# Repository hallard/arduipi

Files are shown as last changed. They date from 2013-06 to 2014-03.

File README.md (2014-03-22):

ArduiPi
=======

ArduiPi is a shield for Raspberry Pi that brings Arduino low level extented I/O to Raspberry Pi.

Detailed Description
====================

Everything is documented on this decicated [page][3]

top  
bottom

**Schematic**  
schematic

**Board**  
![board] (https://raw.github.com/hallard/arduipi/master/ArduiPi-V1.1-brd.png)

Check out news and other projects on my [blog][4] 

[3]: http://hallard.me/arduipi-the-shield-that-brings-arduino-to-raspberry-pi/
[4]: http://hallard.me

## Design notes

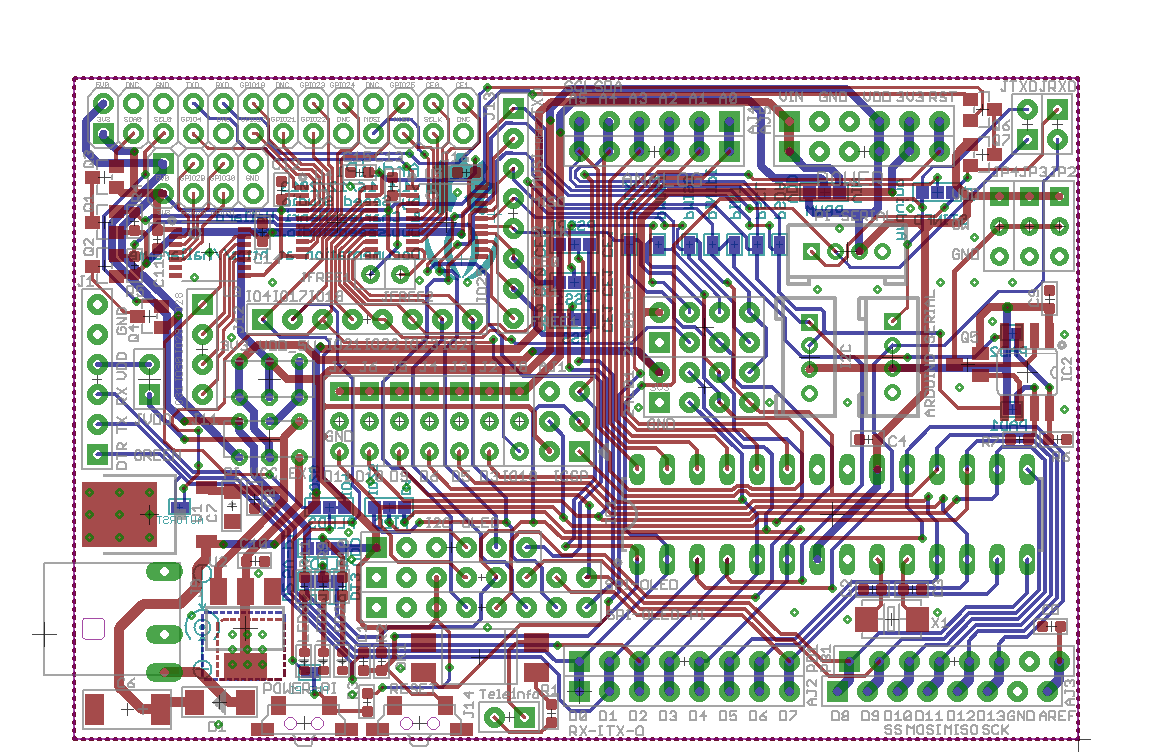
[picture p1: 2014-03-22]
ArduiPi-V1.1-brd.png

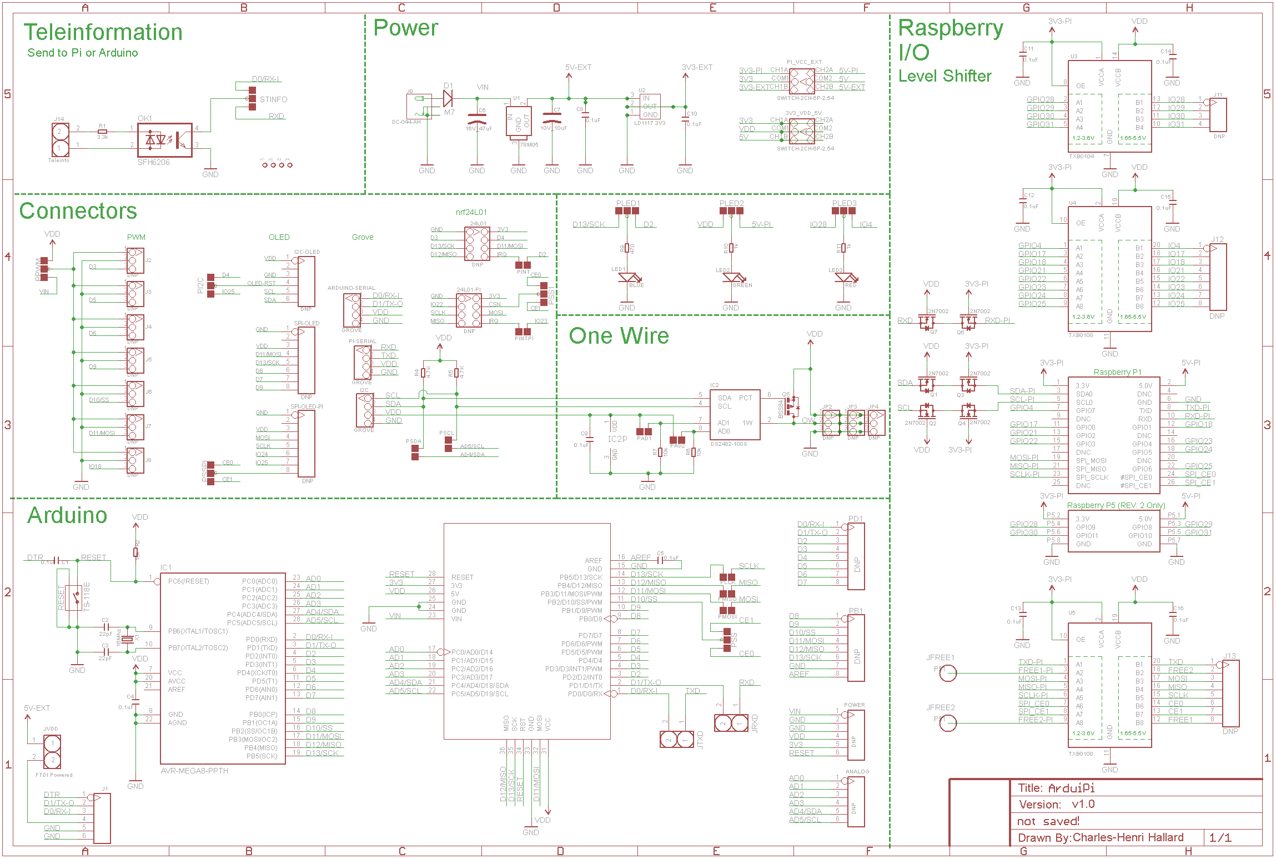
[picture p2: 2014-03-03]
ArduiPi-V1.0-sch.png

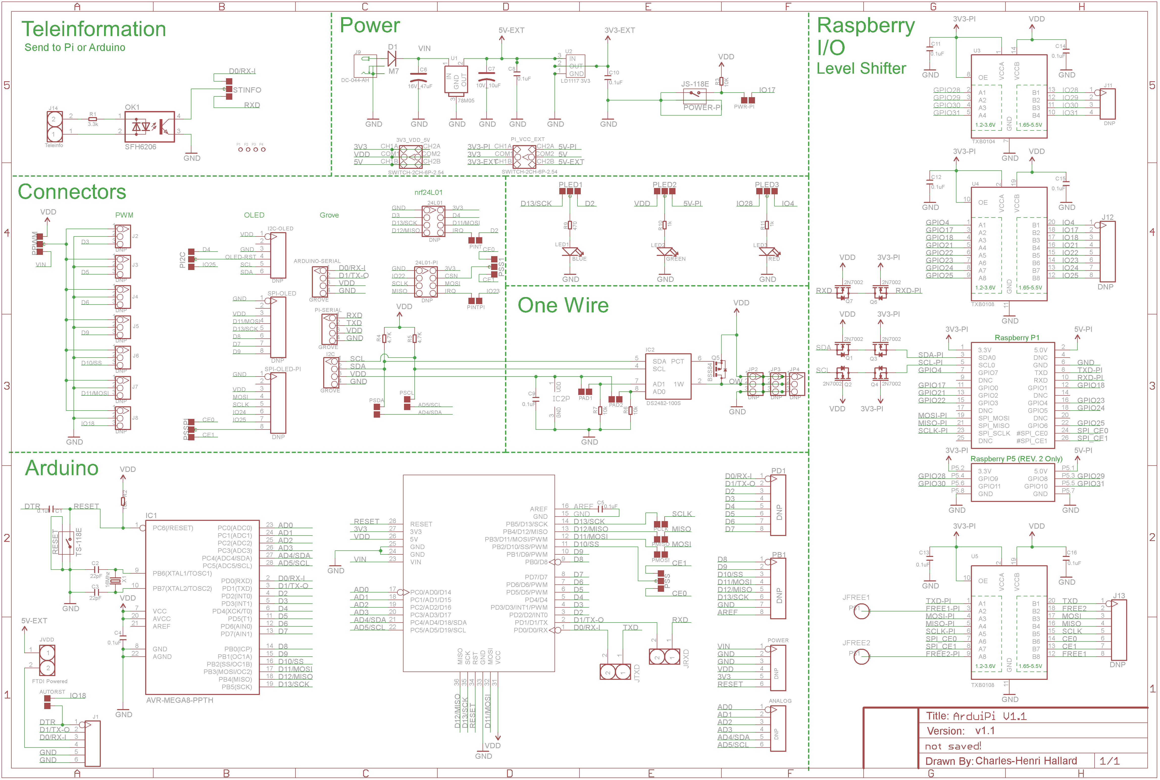
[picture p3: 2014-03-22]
ArduiPi-V1.1-sch.png

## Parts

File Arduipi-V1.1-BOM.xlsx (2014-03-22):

Qty | Part | Value | Package | Seeed Part number | Digikey Part Number | Description
2 | U4, U5 | TXB0108 | TSSOP20 | 156001001 TXB0108PW | 296-21527-1-ND (http://www.digikey.com/product-detail/en/TXB0108PWR/296-21527-1-ND/1305700) | 8-Bit Bi-Directional Level Shifter
1 | U3 | TXB0104 | TSSOP14 | 156002001 TXB0104PWR | 296-21929-1-ND (http://www.digikey.com/product-detail/en/TXB0104PWR/296-21929-1-ND/1629282) | 4-Bit Bi-Directional Level Shifter
1 | OK1 | SFH6206 | DIL4-SMD |  | SFH6206-2T (http://www.digikey.com/product-detail/en/SFH6206-2T/SFH6206-2T-ND/1738581) | Optocoupler, Phototransistor Output, AC Input
6 | Q1, Q2, Q3, Q4, Q6, Q7 | 2N7002 | SOT23 | 044008001
1 | Q5 | CJ2305 | SOT23 | 0440210P1
1 | POWER PI | TS-1188E | 4P-SMD-7X3.5X3.5H | 3100060P1 |  | Switch to power down PI
1 | RESET | TS-1188E | 4P-SMD-7X3.5X3.5H | 3100060P1 |  | Reset Switch, same than the one present on Seeeduino V3
1 | IC2 | DS2482-100S | SO08 |  | DS2482S-100+-ND (http://www.digikey.com/product-detail/en/DS2482S-100%2B/DS2482S-100%2B-ND/1197435) | I2C to 1-Wire Host Adapter/Line Driver
2 | 3V3_VDD_5V | SWITCH-2CH-6P-2.54 | 6P-2CH-2.54-7.6X3.0 | 301002001 |  | Same than the two present on Seeeduino V3
2 | PI_VCC_EXT | SWITCH-2CH-6P-2.54 | 6P-2CH-2.54-7.6X3.0 | 301002001 |  | Same than the two present on Seeeduino V3
1 | U2 | CJT1117-3.3 | SOT-223 | 1310190P1
1 | U1 | CJ78M05 | TO252 | 1300040P1
3 | ARDUINO-SERIAL, I2C, PI-SERIAL | GOVE | 4P-LEADED-2.0 | 3470130P1 |  | Grove Connector, the same than on the Seeeduino V3
1 | J9 | DC-044-AH | DC-404 | 3410010P1 |  | Power Connector, the same than on the Seeeduino V3
12 | C1, C4, C5, C8, C9, C10, C11, C12, C13, C14, C15, C16 | 100nF | 0603 | 0100020P1 |  | Standard surface mount Ceramic Capacitor
1 | IC1 | DIP IC Socket | 2X14P-2.54 Row Spacing 7.62mm | 349003001
1 | insert in IC1 Socket | ATMEGA328P-PU | 28-DIP | 1030050P1 need burn bootloader
2 | C2, C3 | 22pF | 0603 | 0100620P1 |  | Capacitor that goes with AVR crystal
1 | X1 | 16Mhz | 2P-SMD-5X3.2 | 0500290P1 |  | Crystal For AVR
1 | R1 | 1.2k | 0603 | 001095001 |  | Standard surface mount resistor
2 | R6, R7 | 10k | 0603 | 0010170P1 |  | Standard surface mount resistor
1 | R3 | 10k | 0603 | 0010170P1 |  | Standard surface mount resistor
1 | R2 | 10k | 0603 | 0010170P1 |  | Standard surface mount resistor
2 | R4, R5 | 4.7K | 0603 | 0010030P1 |  | Standard surface mount resistor
1 | R9 | 470 | 0603 |  |  | Standard surface mount resistor
2 | R10, R11 | 1K | 0603 |  |  | Standard surface mount resistor
1 | LED1 | BLUE | 0603 | 0330060P1 |  | Standard surface mount BLUE LED
1 | LED2 | GREEN | 0603 | 0330010P1 |  | Standard surface mount GREEN LED
1 | LED3 | RED | 0603 | 0330020P1 |  | Standard surface mount RED LED
1 | D1 | 1N4004 | D2010 | 030003001 |  | Standard diode
1 | C7 | 10uF | CPOL-AVX-A-10UF-10V | 0130040P1 |  | Standard Electrolytic Capacitor
1 | C6 | 47uF | CPOL-AVX-C-47UF-16V | 013015001 |  | Standard Electrolytic Capacitor
1 | PB1 | 2.54-8p female | 8P-2.54 | 3460590P1 |  | Arduino headers, same than on Seeeduino V3
1 | POWER | 2.54-6p female | 6P-2.54-65/35MIL | 346057001 |  | Arduino headers, same than on Seeeduino V3
1 | PD1 | 2.54-8p female | 8P-2.54 | 3460590P1 |  | Arduino headers, same than on Seeeduino V3
1 | ANALOG | 2.54-6p female | 6P-2.54-65/35MIL | 346057001 |  | Arduino headers, same than on Seeeduino V3
1 | RASPBERRY P1 | 2.54-2x13p female |  | 2x13p long female header |  | 2x13 double row 26 pins Raspberry PI Connector
1 | J1 (FTDI connector) | 2.54-6p male | 6P-2.54 | 346075001 | HEADER-6P-2.54 | 6 pin FTDI Header
1 | RASPBERRY P5 | DNP |  | 2x4p long female header |  | DNP
1 | PPWM | DNP | 3P-SMD |  | Solder PAD
1 | PSSPI | DNP | 3P-SMD |  | Solder PAD
7 | J2, J3, J4, J5, J6, J7, J8 | DNP | 3P-2.54 |  | HEADER-3P-2.54
2 | SPI-OLED, SPI-OLED-PI | DNP | 8P-2.54 |  | HEADER-8P-2.54
1 | I2C-OLED | DNP | 6P-2.54 |  | HEADER-6P-2.54
3 | PLED1, PLED2, PLED3 | DNP | 3P-SMD |  | Solder PAD
2 | PAD1, PAD2 | DNP | 2P-SMD |  | Solder PAD
2 | 24L01, 24L01-PI | DNP | 2X4P-2.54 |  | HEADER-2X4P-2.54
2 | PINT, PINT-PI | DNP | 2P-SMD |  | Solder PAD
1 | PSS1 | DNP | 3P-SMD |  | Solder PAD
3 | JP2,JP3,JP4 | DNP | 3P-2.54 |  | HEADER-3P-2.54
1 | PCLK | DNP | 2P-SMD |  | Solder PAD
1 | PMISO | DNP | 2P-SMD |  | Solder PAD
1 | PMOSI | DNP | 2P-SMD |  | Solder PAD
1 | PSS | DNP | 3P-SMD |  | Solder PAD
3 | JVDD, JRXD, JTXD | DNP | 2P-2.54 |  | HEADER-2P-2.54
1 | J14 | DNP | 2P-2.54 |  | HEADER-2P-2.54
1 | J11 | DNP | 4P-2.54 |  | HEADER-4P-2.54
2 | J12, J13 | DNP | 8P-2.54 |  | HEADER-8P-2.54
2 | JFREE1, JFREE2 | DNP | HOLE |  | HOLE
1 | STINFO | DNP | 3P-SMD |  | Solder PAD
1 | PWR-PI | DNP | 2P-SMD |  | Solder PAD
1 | AUTORST | DNP | 2P-SMD |  | Solder PAD
2 | PSDA, PSCL | DNP | 2P-SMD |  | Solder PAD

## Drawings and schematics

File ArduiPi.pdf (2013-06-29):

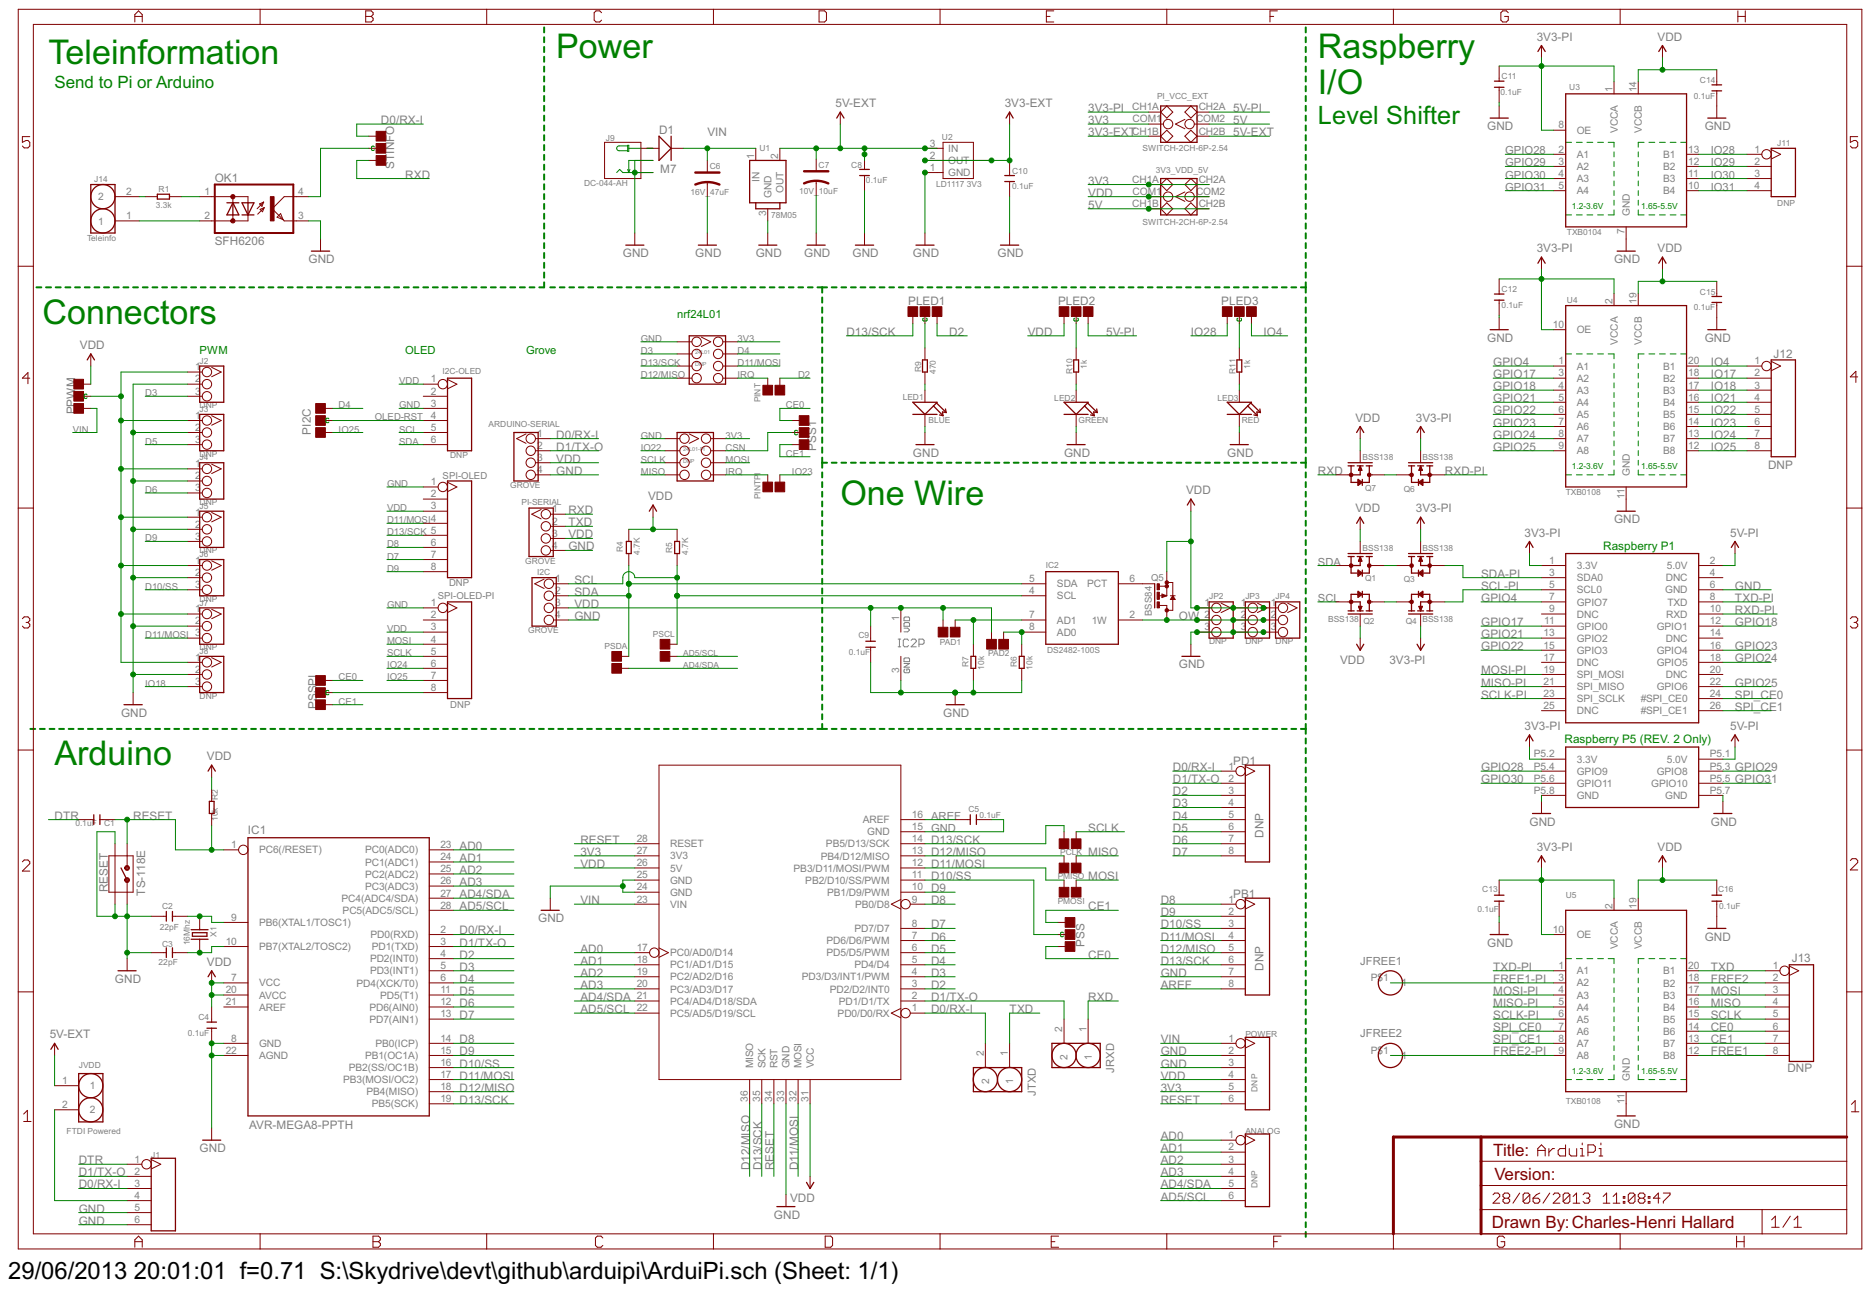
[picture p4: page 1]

Send to Pi or Arduino

AD4/SDA AD5/SCL | 9 PB1/D9/PWM D8 8 PB0/D8 | PMOSI D9 2

Drawn By:Charles-Henri Hallard

29/06/2013 20:01:01 f=0.71 S:\Skydrive\devt\github\arduipi\ArduiPi.sch (Sheet: 1/1)

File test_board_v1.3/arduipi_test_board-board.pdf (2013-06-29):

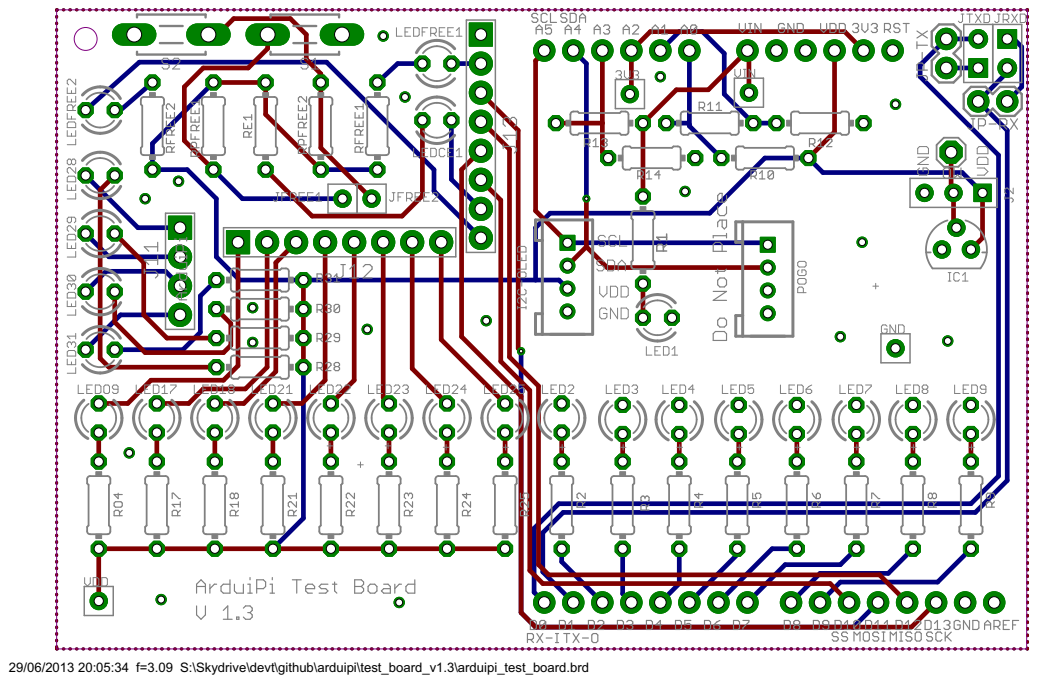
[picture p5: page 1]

29/06/2013 20:05:34 f=3.09 S:\Skydrive\devt\github\arduipi\test_board_v1.3\arduipi_test_board.brd

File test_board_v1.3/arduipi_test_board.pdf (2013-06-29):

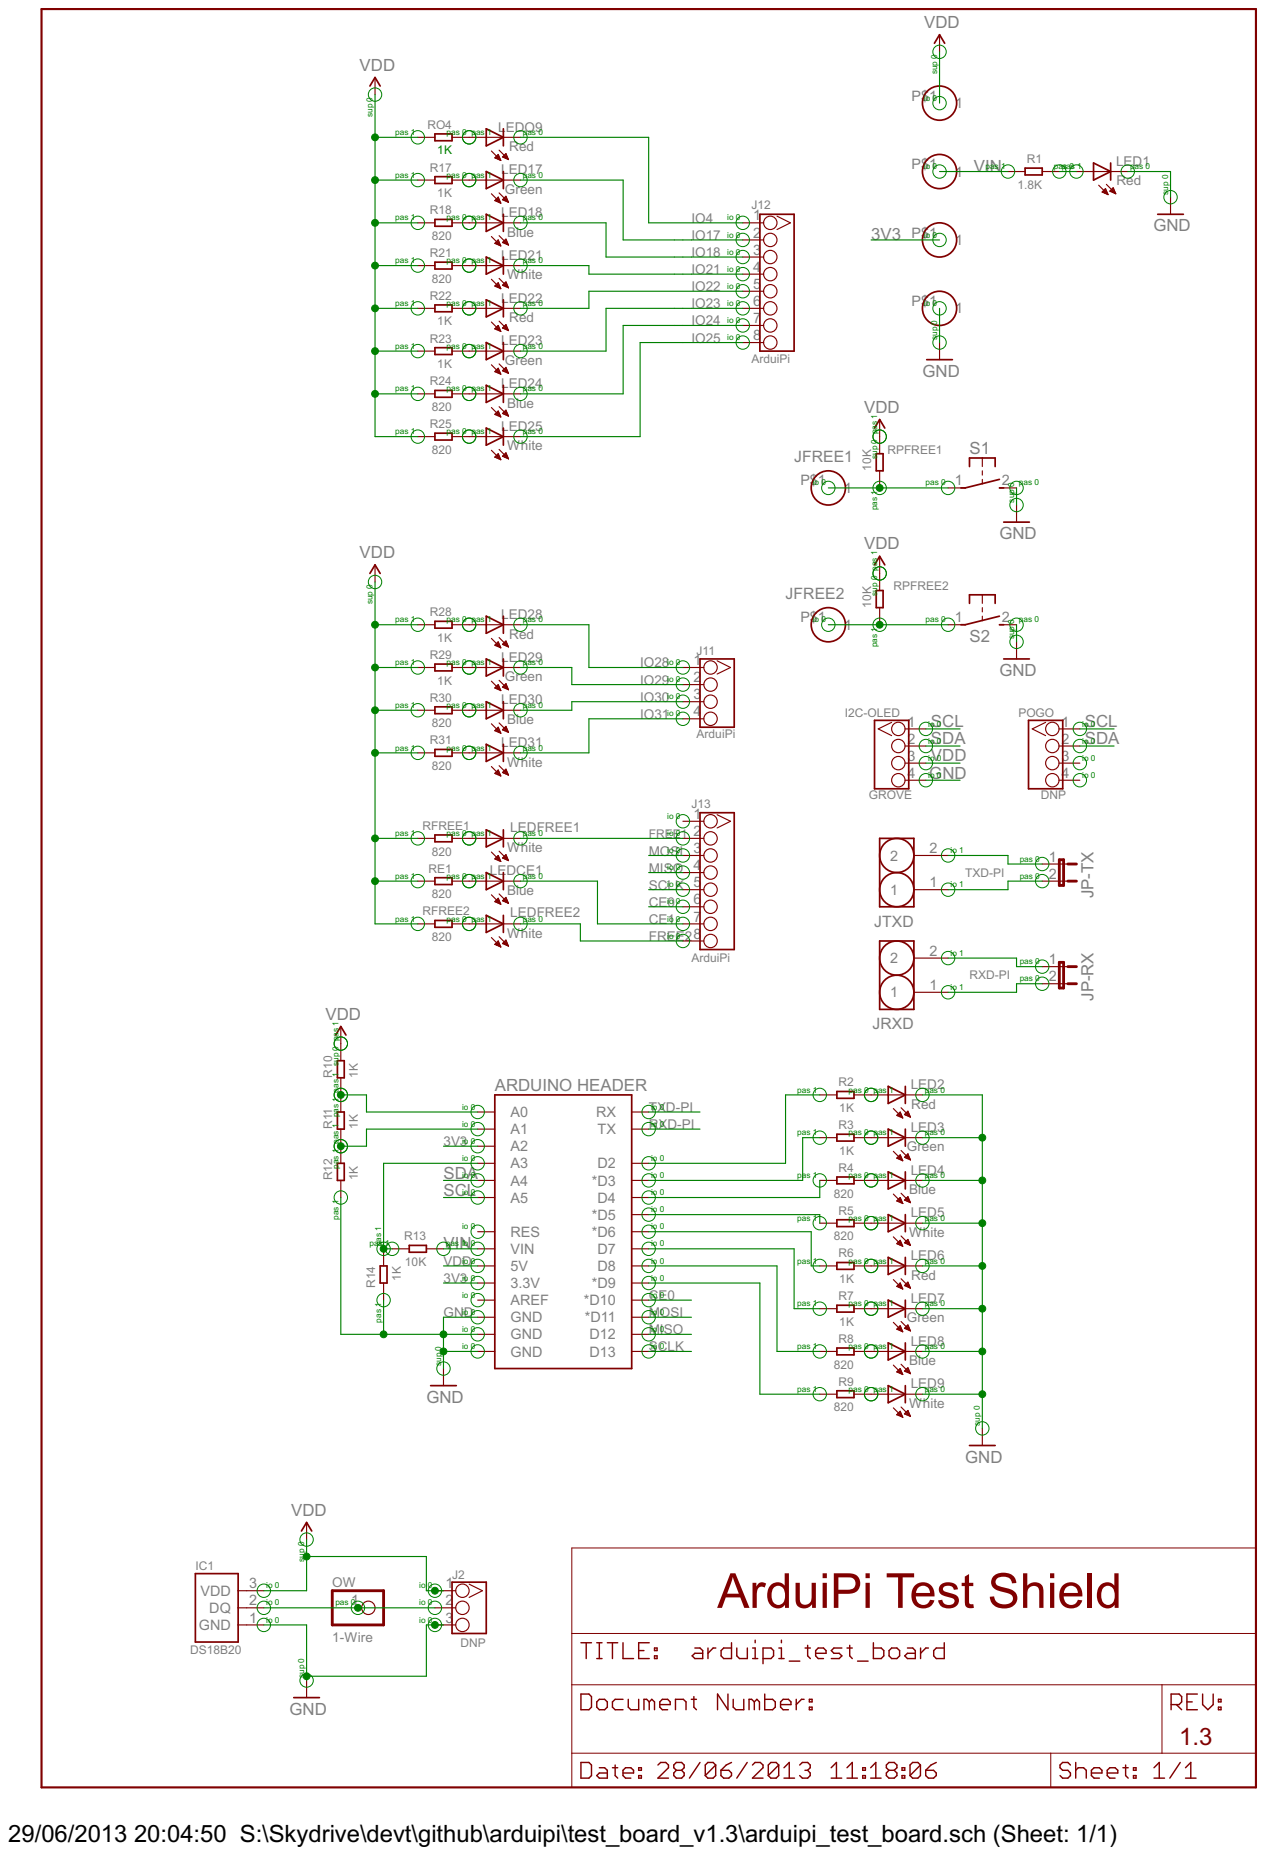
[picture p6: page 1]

pas 1 pas 1 pas 1 pas 1 sup 0 sup 0

pas 1 pas 1 pas 1

29/06/2013 20:04:50 S:\Skydrive\devt\github\arduipi\test_board_v1.3\arduipi_test_board.sch (Sheet: 1/1)

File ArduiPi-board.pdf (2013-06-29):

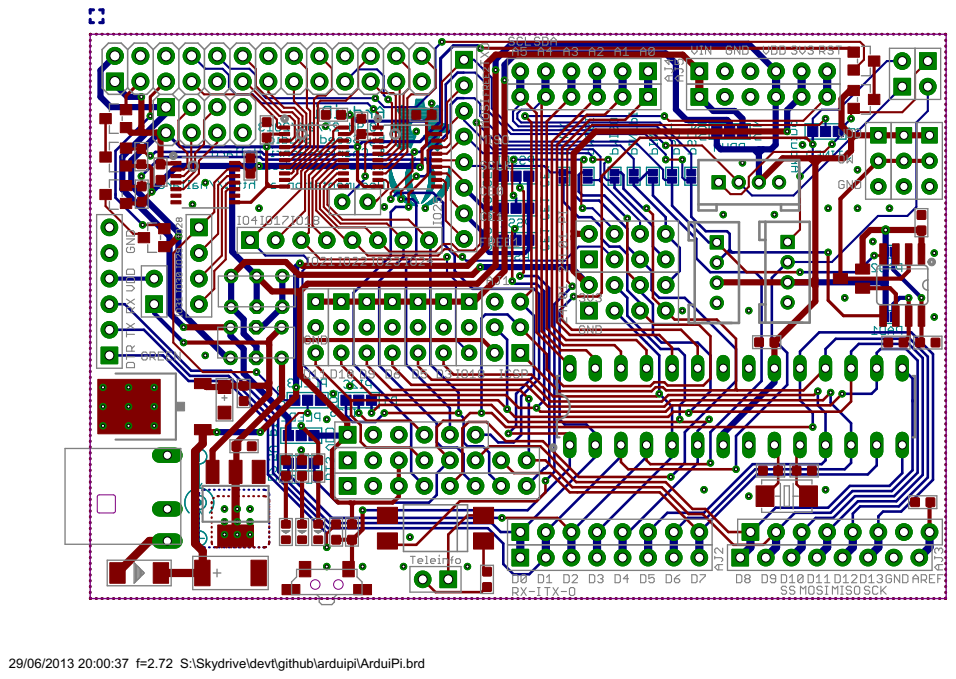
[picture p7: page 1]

29/06/2013 20:00:37 f=2.72 S:\Skydrive\devt\github\arduipi\ArduiPi.brd

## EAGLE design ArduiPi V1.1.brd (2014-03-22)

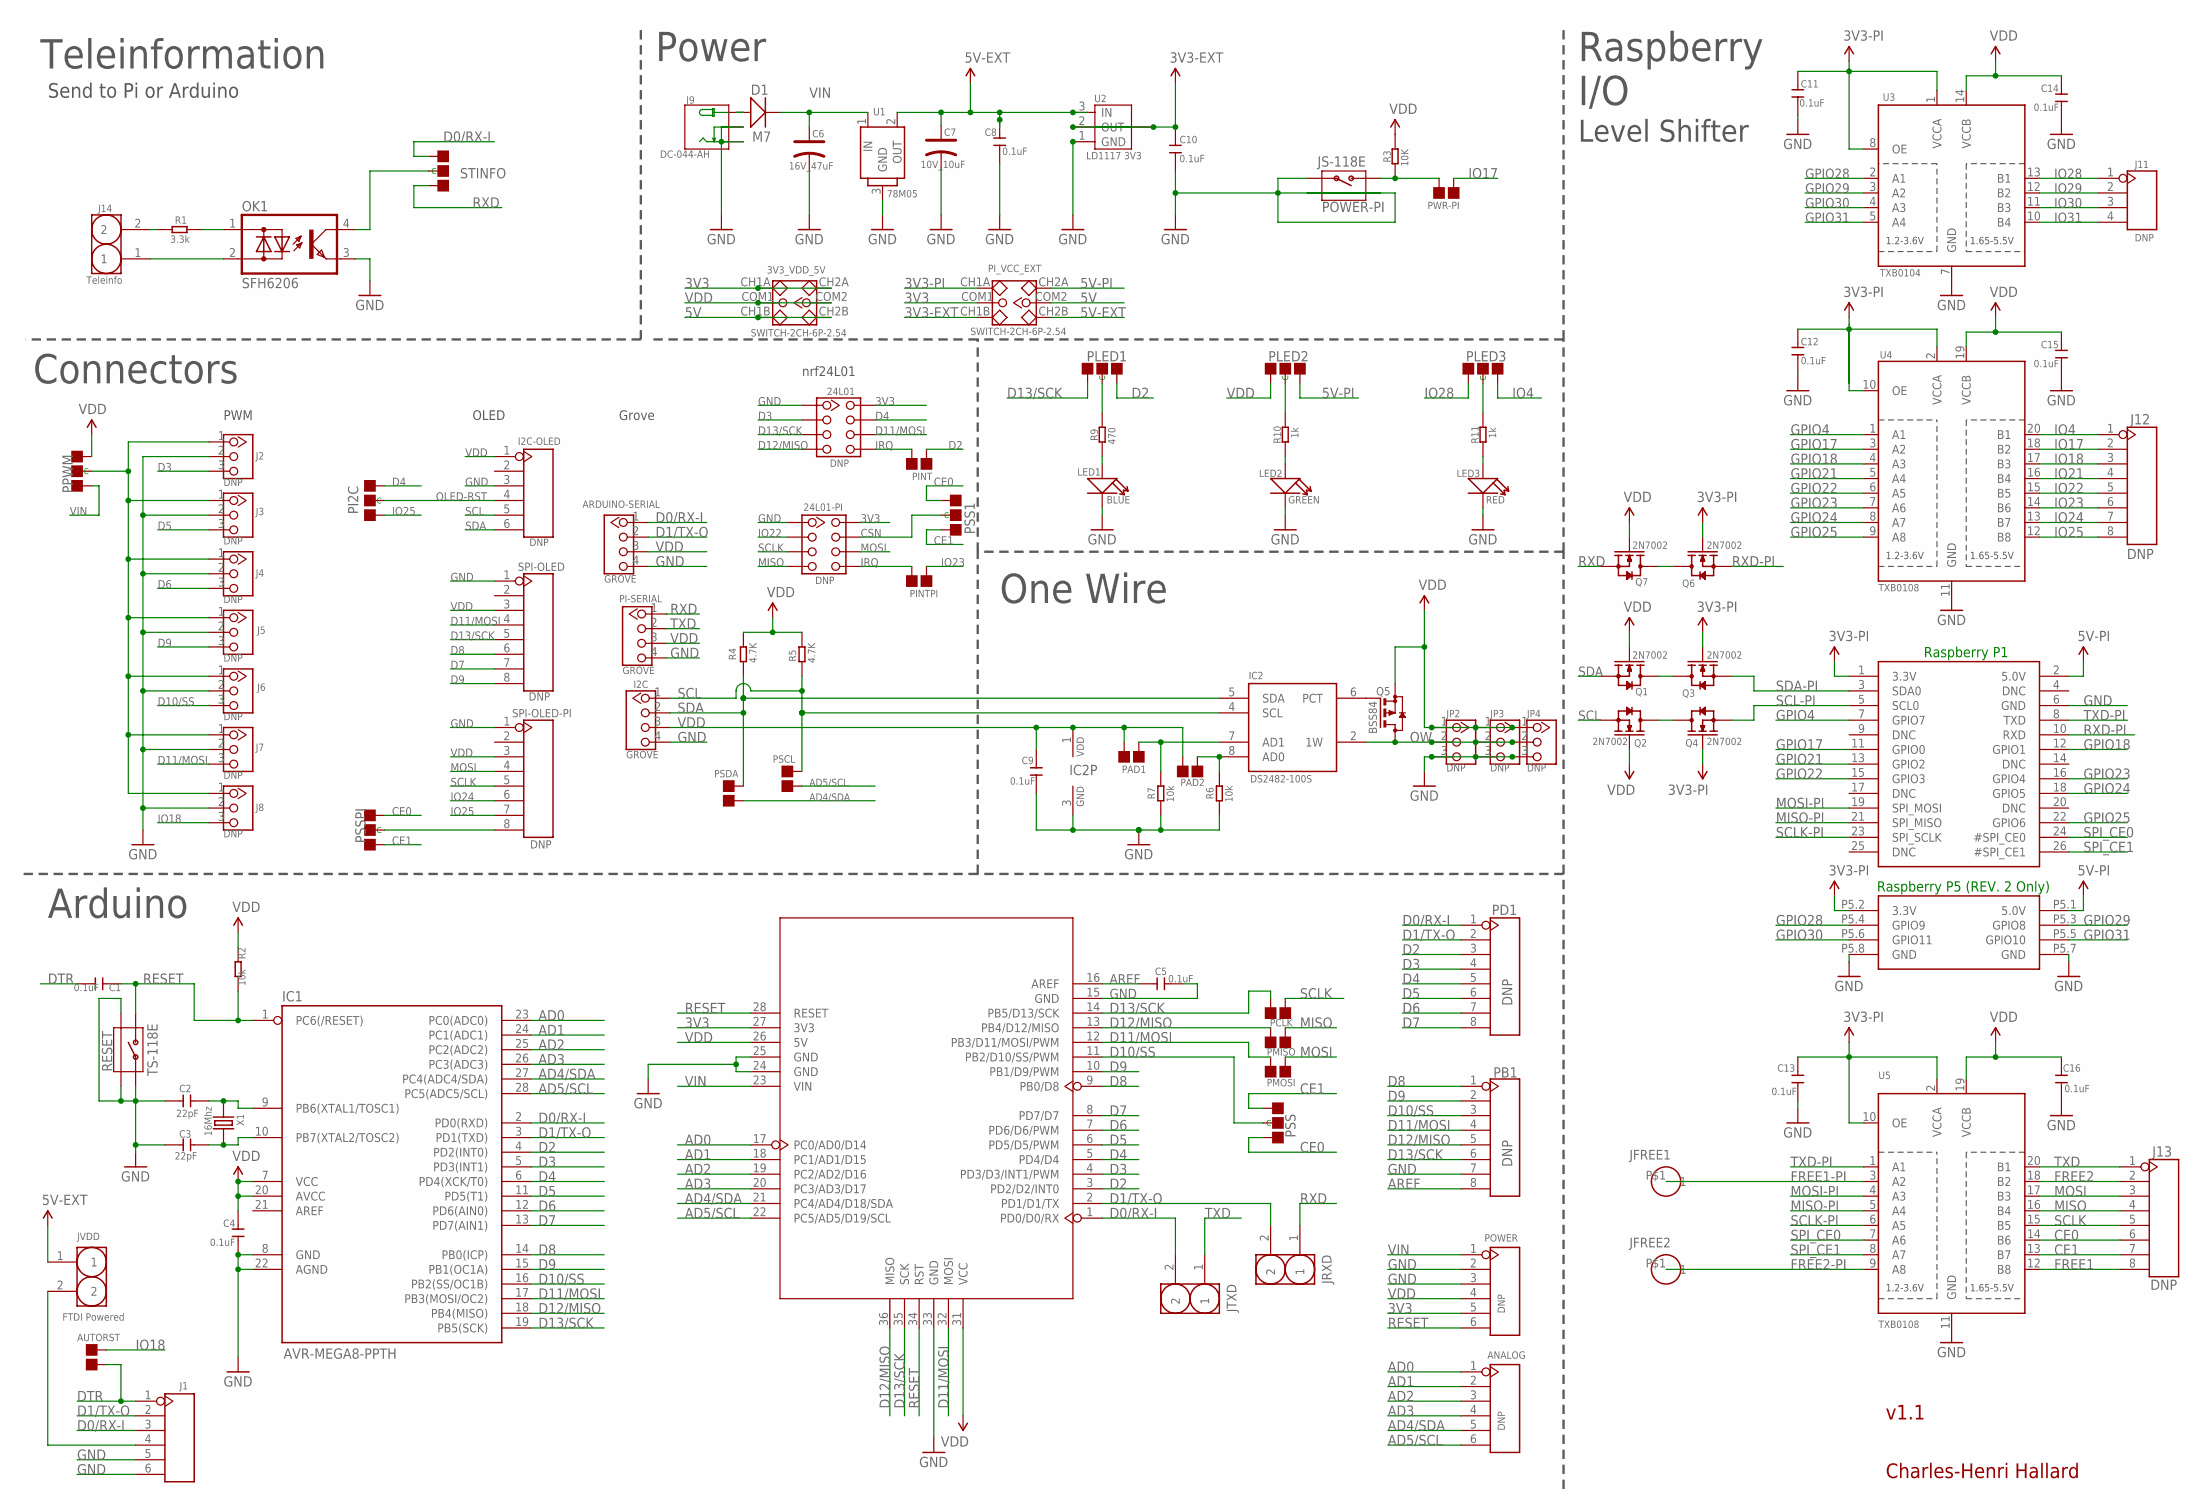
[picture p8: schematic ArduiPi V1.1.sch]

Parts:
3V3_VDD_5V: SWITCH-2CH-6P-2.54; 6P-2CH-2.54-7.6X3.0
24L01, 24L01-PI: DNP; 2X4P-2.54
ANALOG: DNP; 6P-2.54-65/35MIL
ARDUINO-SERIAL: GROVE; 4P-LEADED-2.0
AUTORST: PSDA; 2P-SMD-1.78X1.27
C1, C4, C5, C8, C9, C10, C11, C12, C13, C14, C15, C16: 0.1uF; C0603
C2, C3: 22pF; C0603
C6: 16V_47uF; AVX-C
C7: 10V_10uF; AVX-A
D1: M7; D2010
I2C: GROVE; 4P-LEADED-2.0
I2C-OLED: DNP; 6P-2.54-65/35MIL
IC1: AVR-MEGA8-PPTH; DIL28-3
IC2: DS2482-100S; SO08
J1: HEADER-6P-65/35MIL; 6P-2.54-65/35MIL
J2, J3, J4, J5, J6, J7, J8: DNP; 3P-2.54
J9: DC-044-AH; DC-044
J11: DNP; 4P-65/35MIL
J12, J13: DNP; 8P-2.54-65/35MIL
J14: Teleinfo; 2P-2.54
JFREE1, JFREE2: HEADER-1P-32; 1P-60/32MIL
JP2, JP3, JP4: DNP; 3P-2.54
JRXD: J2; 2P-2.54
JTXD: J1; 2P-2.54
JVDD: FTDI Powered; 2P-2.54
LED1: BLUE; LED-0603
LED2: GREEN; LED-0603
LED3: RED; LED-0603
OK1: SFH6206; DIL4-SMD
PAD1: PAD1; 2P-SMD-1.78X1.27; PARTNO DNP
PAD2: PAD2; 2P-SMD-1.78X1.27; PARTNO DNP
PB1: DNP; 8P-2.54-65/35MIL
PCLK: PCLK; 2P-SMD-1.78X1.27
PD1: DNP; 8P-2.54-65/35MIL
PI2C: PAD-JUMPER-3P-40*40; 3P-SMD-4.1X1.5; PARTNO DNP
PI-P1: PI-P1; RASPBERRYPI_SHIELD
PI-SERIAL: GROVE; 4P-LEADED-2.0
PINT: PINT; 2P-SMD-1.78X1.27
PINTPI: PINTPI; 2P-SMD-1.78X1.27
PI_VCC_EXT: SWITCH-2CH-6P-2.54; 6P-2CH-2.54-7.6X3.0
PLED1, PLED3: PAD-JUMPER-3P-40*40; 3P-SMD-4.1X1.5; PARTNO DNP
PLED2: PAD-JUMPER-3P-40*40; 3P-SMD-4.1X1.5
PMISO: PMISO; 2P-SMD-1.78X1.27
PMOSI: PMOSI; 2P-SMD-1.78X1.27
POWER: DNP; 6P-2.54-65/35MIL
POWER-PI: JS-118E; 4P-SMD-7X3.5X3.5H
PPWM: PAD-JUMPER-3P-40*40; 3P-SMD-4.1X1.5; PARTNO DNP
PSCL: PSCL; 2P-SMD-1.78X1.27
PSDA: PSDA; 2P-SMD-1.78X1.27
PSS: PAD-JUMPER-3P-40*40; 3P-SMD-4.1X1.5
PSS1: PAD-JUMPER-3P-40*40; 3P-SMD-4.1X1.5; PARTNO DNP
PSSPI: PAD-JUMPER-3P-40*40; 3P-SMD-4.1X1.5; PARTNO DNP
PWR-PI: PINT; 2P-SMD-1.78X1.27
Q1, Q2, Q3, Q4, Q6, Q7: 2N7002; SOT23
Q5: BSS84; SOT23
R1: 3.3k; R0603
R2, R6, R7: 10k; R0603
R3: 10K; R0603
R4, R5: 4.7K; R0603
R9: 470; R0603
R10, R11: 1k; R0603
RESET: TS-118E; 4P-SMD-7X3.5X3.5H
SPI-OLED: DNP; 8P-2.54-65/35MIL
SPI-OLED-PI: DNP; 8P-2.54-65/35MIL
STINFO: PAD-JUMPER-3P-40*40; 3P-SMD-4.1X1.5
U1: 78M05; TO252
U2: LD1117 3V3; SOT-223
U3: TXB0104; TSSOP14
U4, U5: TXB0108; TSSOP20
U6: ARDUINO'W/-SILK; ARDUINO
X1: 16Mhz; 2P-SMD-5X3.2

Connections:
3V3: 3V3_VDD_5V.CH1A, 3V3_VDD_5V.CH2A, 24L01.8, 24L01-PI.8, PI_VCC_EXT.COM1, POWER.5, U6.27 (3V3)
3V3-EXT: C10.2, PI_VCC_EXT.CH1B, U2.2 (OUT), U2.TER (TAB)
3V3-PI: C11.1, C12.1, C13.1, PI-P1.1 (3.3V), PI-P1.P5.2 (3.3V), PI_VCC_EXT.CH1A, Q3.1 (G), Q4.1 (G), Q6.1 (G), U3.1 (VCCA), U3.8 (OE), U4.2 (VCCA), U4.10 (OE), U5.2 (VCCA), U5.10 (OE)
5V: 3V3_VDD_5V.CH1B, 3V3_VDD_5V.CH2B, PI_VCC_EXT.COM2
5V-EXT: C7.+, C8.2, JVDD.1, PI_VCC_EXT.CH2B, U1.2 (OUT), U2.3 (IN)
5V-PI: PI-P1.2 (5.0V), PI-P1.P5.1 (5.0V), PI_VCC_EXT.CH2A, PLED2.11 (R)
AD0: ANALOG.1, IC1.23 (PC0(ADC0)), U6.17 (PC0/AD0/D14)
AD1: ANALOG.2, IC1.24 (PC1(ADC1)), U6.18 (PC1/AD1/D15)
AD2: ANALOG.3, IC1.25 (PC2(ADC2)), U6.19 (PC2/AD2/D16)
AD3: ANALOG.4, IC1.26 (PC3(ADC3)), U6.20 (PC3/AD3/D17)
AD4/SDA: ANALOG.5, IC1.27 (PC4(ADC4/SDA)), PSDA.1, U6.21 (PC4/AD4/D18/SDA)
AD5/SCL: ANALOG.6, IC1.28 (PC5(ADC5/SCL)), PSCL.1, U6.22 (PC5/AD5/D19/SCL)
AREF: C5.1, PB1.8, U6.16 (AREF)
CE0: J13.6, PSS.11 (R), PSS1.00 (L), PSSPI.11 (R), U5.14 (B6)
CE1: J13.7, PSS.00 (L), PSS1.11 (R), PSSPI.00 (L), U5.13 (B7)
CSN: 24L01-PI.7, PSS1.MM (C)
D0/RX-I: ARDUINO-SERIAL.1, IC1.2 (PD0(RXD)), J1.3, JTXD.2, PD1.1, STINFO.00 (L), U6.1 (PD0/D0/RX)
D1/TX-O: ARDUINO-SERIAL.2, IC1.3 (PD1(TXD)), J1.2, JRXD.2, PD1.2, U6.2 (PD1/D1/TX)
D2: IC1.4 (PD2(INT0)), PD1.3, PINT.1, PLED1.11 (R), U6.3 (PD2/D2/INT0)
D3: 24L01.2, IC1.5 (PD3(INT1)), J2.3, PD1.4, U6.4 (PD3/D3/INT1/PWM)
D4: 24L01.7, IC1.6 (PD4(XCK/T0)), PD1.5, PI2C.11 (R), U6.5 (PD4/D4)
D5: IC1.11 (PD5(T1)), J3.3, PD1.6, U6.6 (PD5/D5/PWM)
D6: IC1.12 (PD6(AIN0)), J4.3, PD1.7, U6.7 (PD6/D6/PWM)
D7: IC1.13 (PD7(AIN1)), PD1.8, SPI-OLED.7, U6.8 (PD7/D7)
D8: IC1.14 (PB0(ICP)), PB1.1, SPI-OLED.6, U6.9 (PB0/D8)
D9: IC1.15 (PB1(OC1A)), J5.3, PB1.2, SPI-OLED.8, U6.10 (PB1/D9/PWM)
D10/SS: IC1.16 (PB2(SS/OC1B)), J6.3, PB1.3, PSS.MM (C), U6.11 (PB2/D10/SS/PWM)
D11/MOSI: 24L01.6, IC1.17 (PB3(MOSI/OC2)), J7.3, PB1.4, PMOSI.2, SPI-OLED.4, U6.12 (PB3/D11/MOSI/PWM), U6.32 (MOSI)
D12/MISO: 24L01.4, IC1.18 (PB4(MISO)), PB1.5, PMISO.2, U6.13 (PB4/D12/MISO), U6.36 (MISO)
D13/SCK: 24L01.3, IC1.19 (PB5(SCK)), PB1.6, PCLK.2, PLED1.00 (L), SPI-OLED.5, U6.14 (PB5/D13/SCK), U6.35 (SCK)
DTR: AUTORST.1, C1.2, J1.1
FREE1: J13.8, U5.12 (B8)
FREE1-PI: JFREE1.P$1, U5.3 (A2)
FREE2: J13.2, U5.18 (B2)
FREE2-PI: JFREE2.P$1, U5.9 (A8)
GND: 24L01.1, 24L01-PI.1, ARDUINO-SERIAL.4, C2.2, C3.2, C4.1, C5.2, C6.-, C7.-, C8.1, C9.2, C10.1, C11.2, C12.2, C13.2, C14.2, C15.2, C16.2, I2C.4, I2C-OLED.3, IC1.8 (GND), IC1.22 (AGND), IC2.3 (GND), J1.5, J1.6, J2.2, J3.2, J4.2, J5.2, J6.2, J7.2, J8.2, J9.-, J9.CDN, JP2.3, JP3.3, JP4.3, LED1.-, LED2.-, LED3.-, OK1.3 (E), PB1.7, PI-P1.6 (GND), PI-P1.P5.7 (GND), PI-P1.P5.8 (GND), PI-SERIAL.4, POWER.2, POWER.3, POWER-PI.1, POWER-PI.S1, POWER-PI.S2, R6.1, R7.1, RESET.1, RESET.S1, RESET.S2, SPI-OLED.1, SPI-OLED-PI.1, U1.3 (GND), U2.1 (GND), U3.7 (GND), U4.11 (GND), U5.11 (GND), U6.15 (GND), U6.24 (GND), U6.25 (GND), U6.33 (GND)
GPIO4: PI-P1.7 (GPIO7), U4.1 (A1)
GPIO17: PI-P1.11 (GPIO0), U4.3 (A2)
GPIO18: PI-P1.12 (GPIO1), U4.4 (A3)
GPIO21: PI-P1.13 (GPIO2), U4.5 (A4)
GPIO22: PI-P1.15 (GPIO3), U4.6 (A5)
GPIO23: PI-P1.16 (GPIO4), U4.7 (A6)
GPIO24: PI-P1.18 (GPIO5), U4.8 (A7)
GPIO25: PI-P1.22 (GPIO6), U4.9 (A8)
GPIO28: PI-P1.P5.4 (GPIO9), U3.2 (A1)
GPIO29: PI-P1.P5.3 (GPIO8), U3.3 (A2)
GPIO30: PI-P1.P5.6 (GPIO11), U3.4 (A3)
GPIO31: PI-P1.P5.5 (GPIO10), U3.5 (A4)
IO4: J12.1, PLED3.11 (R), U4.20 (B1)
IO17: J12.2, PWR-PI.1, U4.18 (B2)
IO18: AUTORST.2, J8.3, J12.3, U4.17 (B3)
IO21: J12.4, U4.16 (B4)
IO22: 24L01-PI.2, J12.5, U4.15 (B5)
IO23: J12.6, PINTPI.1, U4.14 (B6)
IO24: J12.7, SPI-OLED-PI.6, U4.13 (B7)
IO25: J12.8, PI2C.00 (L), SPI-OLED-PI.7, U4.12 (B8)
IO28: J11.1, PLED3.00 (L), U3.13 (B1)
IO29: J11.2, U3.12 (B2)
IO30: J11.3, U3.11 (B3)
IO31: J11.4, U3.10 (B4)
IRQ: 24L01.5, 24L01-PI.5, PINT.2, PINTPI.2
MISO: 24L01-PI.4, J13.4, PMISO.1, U5.16 (B4)
MISO-PI: PI-P1.21 (SPI_MISO), U5.5 (A4)
MOSI: 24L01-PI.6, J13.3, PMOSI.1, SPI-OLED-PI.4, U5.17 (B3)
MOSI-PI: PI-P1.19 (SPI_MOSI), U5.4 (A3)
unnamed: OK1.4 (C), STINFO.MM (C)
unnamed: IC2.8 (AD0), PAD2.1, R6.2
unnamed: C3.1, IC1.10 (PB7(XTAL2/TOSC2)), X1.1
unnamed: C2.1, IC1.9 (PB6(XTAL1/TOSC1)), X1.2
unnamed: Q1.3 (D), Q3.3 (D)
unnamed: Q2.3 (D), Q4.3 (D)
unnamed: Q6.3 (D), Q7.3 (D)
unnamed: OK1.1 (AC1), R1.1
unnamed: J14.1, OK1.2 (AC2)
unnamed: J1.4, JVDD.2
unnamed: IC2.7 (AD1), PAD1.1, R7.2
unnamed: D1.+, J9.+
unnamed: LED3.+, R11.2
unnamed: J14.2, R1.2
unnamed: IC2.6 (PCT), Q5.1 (G)
unnamed: PLED1.MM (C), R9.1
unnamed: LED1.+, R9.2
unnamed: LED2.+, R10.2
unnamed: PLED3.MM (C), R11.1
unnamed: PLED2.MM (C), R10.1
unnamed: J2.1, J3.1, J4.1, J5.1, J6.1, J7.1, J8.1, PPWM.MM (C)
unnamed: POWER-PI.2, PWR-PI.2, R3.2
OLED-RST: I2C-OLED.4, PI2C.MM (C)
OW: IC2.2 (1W), JP2.2, JP3.2, JP4.2, Q5.3 (D)
RESET: C1.1, IC1.1 (PC6(/RESET)), POWER.6, R2.2, RESET.2, U6.28 (RESET), U6.34 (RST)
RXD: JRXD.1, PI-SERIAL.1, Q7.2 (S), STINFO.11 (R)
RXD-PI: PI-P1.10 (RXD), Q6.2 (S)
SCL: I2C.1, I2C-OLED.5, IC2.4 (SCL), PSCL.2, Q2.2 (S), R5.1
SCL-PI: PI-P1.5 (SCL0), Q4.2 (S)
SCLK: 24L01-PI.3, J13.5, PCLK.1, SPI-OLED-PI.5, U5.15 (B5)
SCLK-PI: PI-P1.23 (SPI_SCLK), U5.6 (A5)
SDA: I2C.2, I2C-OLED.6, IC2.5 (SDA), PSDA.2, Q1.2 (S), R4.1
SDA-PI: PI-P1.3 (SDA0), Q3.2 (S)
SPI_CE0: PI-P1.24 (#SPI_CE0), U5.7 (A6)
SPI_CE1: PI-P1.26 (#SPI_CE1), U5.8 (A7)
SSPI: PSSPI.MM (C), SPI-OLED-PI.8
TXD: J13.1, JTXD.1, PI-SERIAL.2, U5.20 (B1)
TXD-PI: PI-P1.8 (TXD), U5.1 (A1)
VDD: 3V3_VDD_5V.COM1, 3V3_VDD_5V.COM2, ARDUINO-SERIAL.3, C4.2, C9.1, C14.1, C15.1, C16.1, I2C.3, I2C-OLED.1, IC1.7 (VCC), IC1.20 (AVCC), IC2.1 (VDD), JP2.1, JP3.1, JP4.1, PAD1.2, PAD2.2, PI-SERIAL.3, PLED2.00 (L), POWER.4, PPWM.00 (L), Q1.1 (G), Q2.1 (G), Q5.2 (S), Q7.1 (G), R2.1, R3.1, R4.2, R5.2, SPI-OLED.3, SPI-OLED-PI.3, U3.14 (VCCB), U4.19 (VCCB), U5.19 (VCCB), U6.26 (5V), U6.31 (VCC)
VIN: C6.+, D1.-, POWER.1, PPWM.11 (R), U1.1 (IN), U6.23 (VIN)

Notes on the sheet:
Teleinformation
Power
Charles-Henri Hallard
Raspberry I/O
Level Shifter
Send to Pi or Arduino
One Wire
Connectors
Arduino
Raspberry P1
Raspberry P5 (REV. 2 Only)
PWM
OLED
Grove
nrf24L01
v1.1

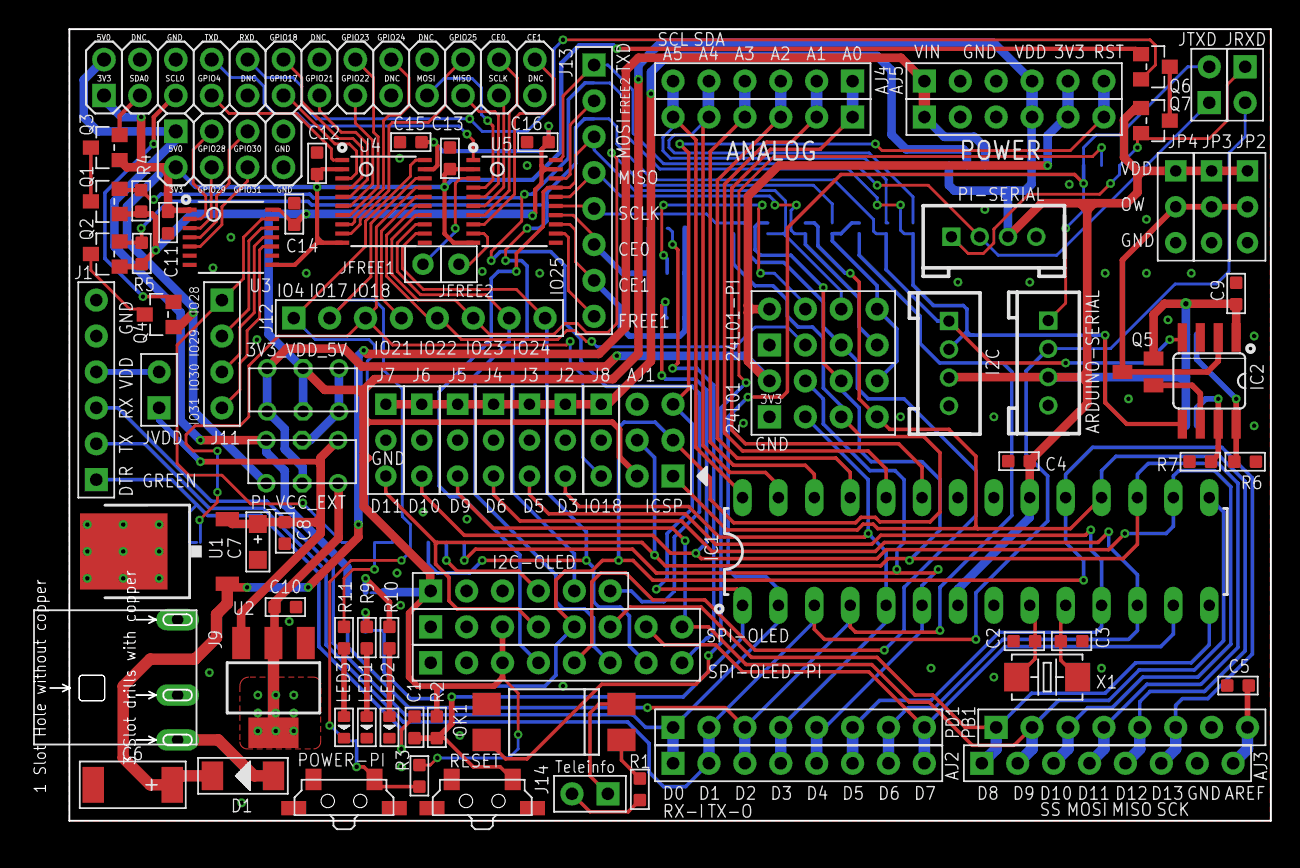
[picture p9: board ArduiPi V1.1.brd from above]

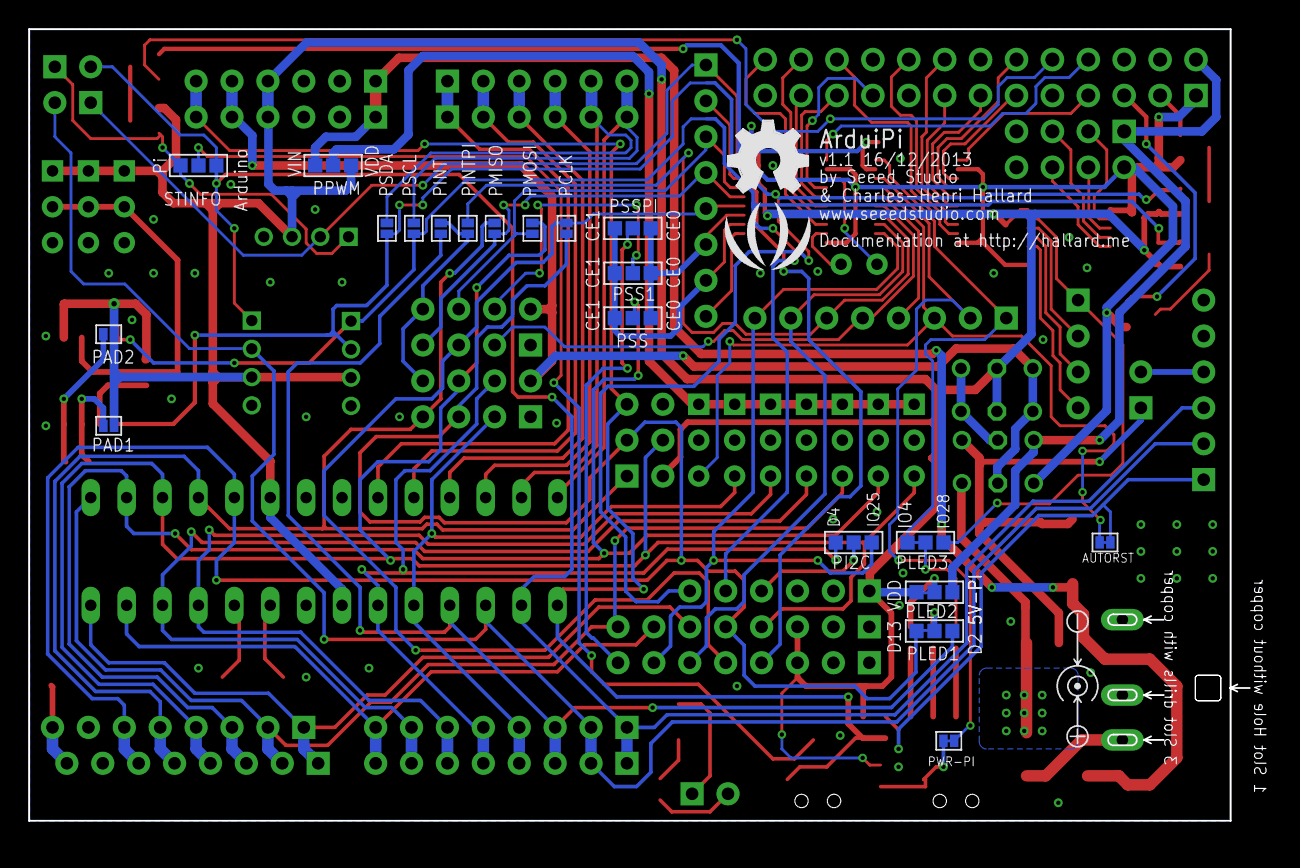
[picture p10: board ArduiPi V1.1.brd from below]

Board: 2 copper layers, 86.4 x 56.0 mm, 107 parts (22 on the bottom side), 105 nets.

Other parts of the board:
U$3: LOGO_SILK
U$6: OSHW_FILLX200_NOTEXT

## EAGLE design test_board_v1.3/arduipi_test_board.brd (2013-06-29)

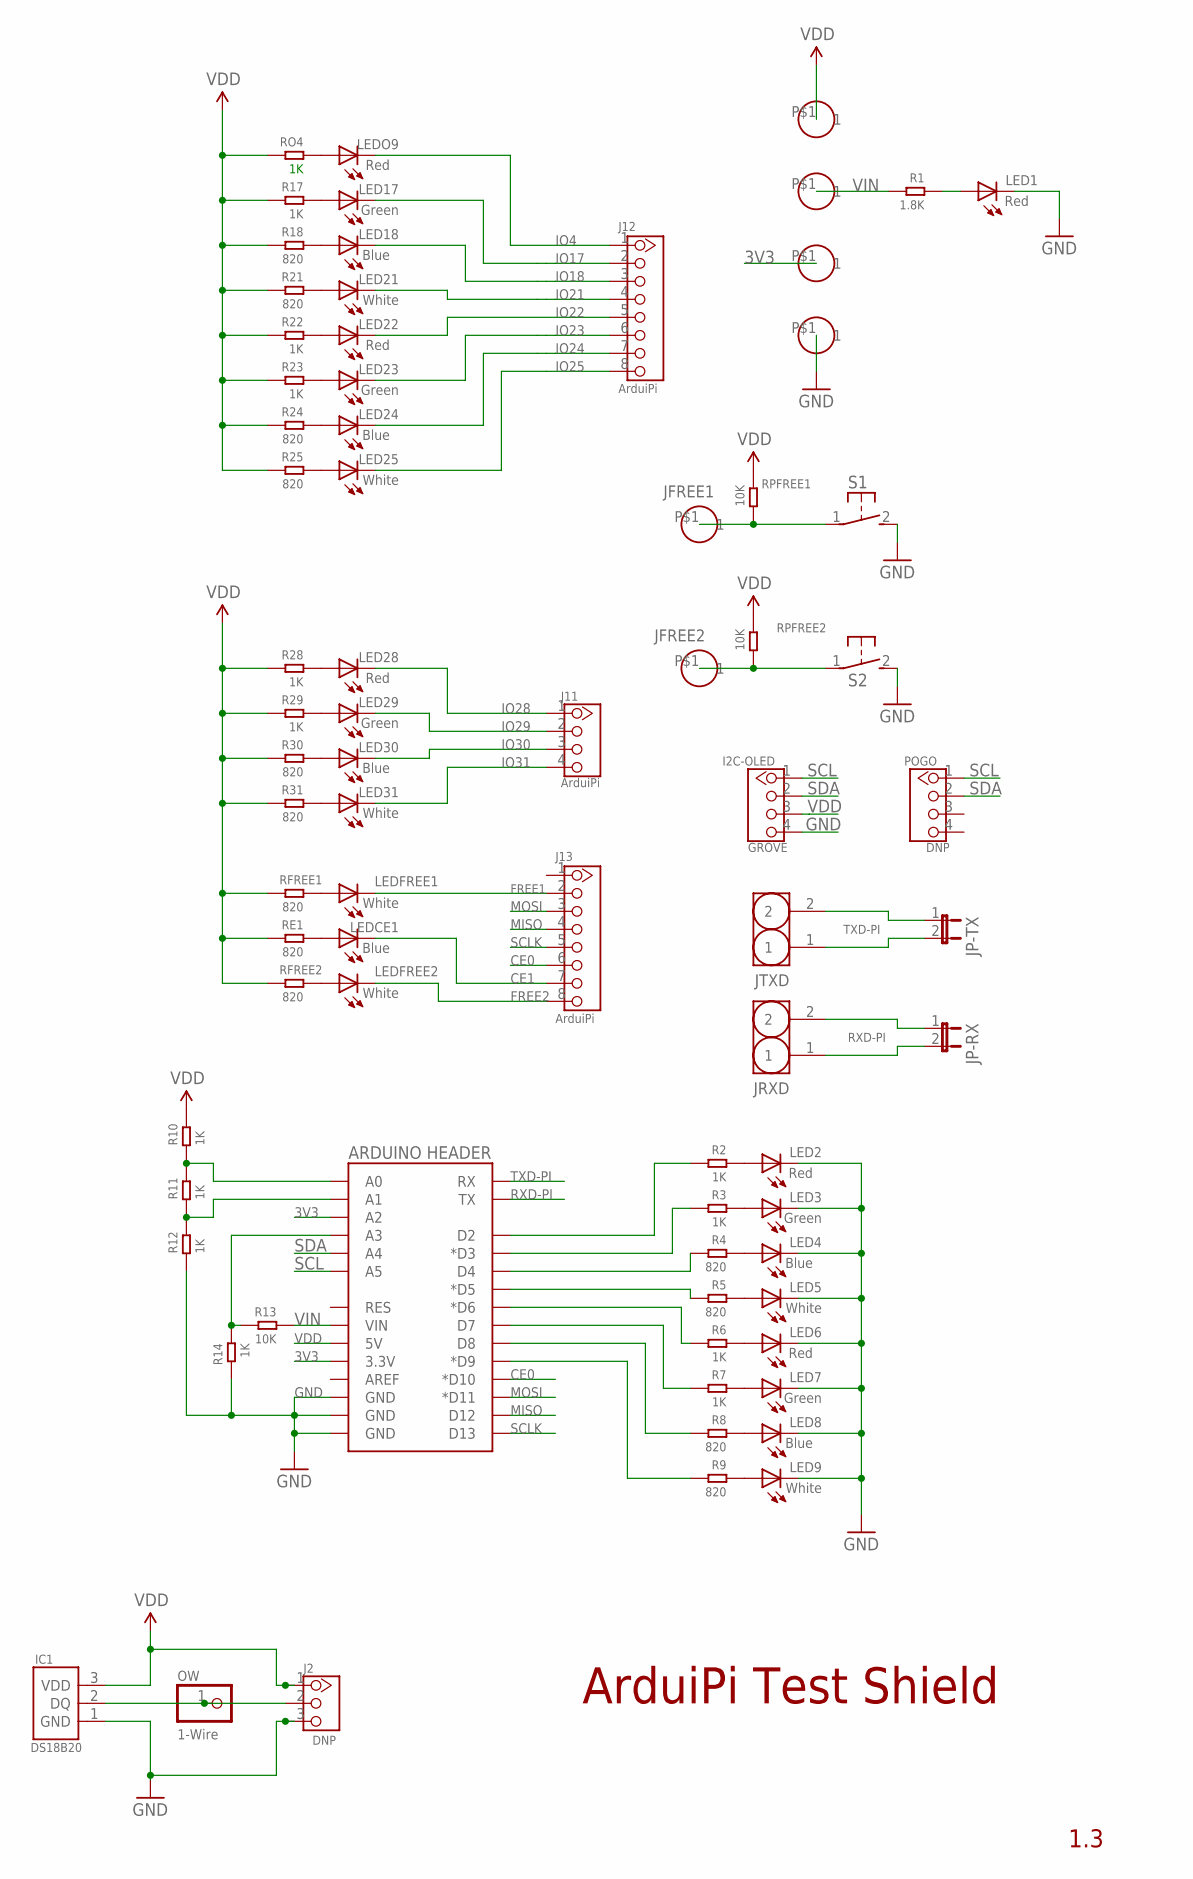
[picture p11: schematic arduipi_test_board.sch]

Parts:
3V3: HEADER-1P-32; 1P-60/32MIL
GND: HEADER-1P-32; 1P-60/32MIL
I2C-OLED: GROVE; 4P-LEADED-2.0
IC1: DS18B20; TO-92-TRIANGLE
J2: DNP; 3P-2.54
J11: ArduiPi; 4P-2.54-80/40MIL
J12, J13: ArduiPi; 8P-2.54-80/40MIL
JFREE1, JFREE2: HEADER-1P-32; 1P-60/32MIL
JP-RX: JUMPER-2PTH; 1X02
JP-TX: JUMPER-2PTH; 1X02
JRXD: J2; 2P-2.54
JTXD: J1; 2P-2.54
LED1, LED2, LED6, LED22, LED28: Red; LED3MM
LED3, LED7, LED17, LED23, LED29: Green; LED3MM
LED4, LED8, LED18, LED24, LED30: Blue; LED3MM
LED5, LED9, LED21, LED25, LED31: White; LED3MM
LEDCE1: Blue; LED3MM
LEDFREE1, LEDFREE2: White; LED3MM
LEDO9: Red; LED3MM
OW: 1-Wire; 1X01
POGO: DNP; 4P-LEADED-2.0
R1: 1.8K; 0204/7
R2, R3, R6, R7, R10, R11, R12, R14, R17, R22, R23, R28, R29: 1K; 0204/7
R4, R5, R8, R9, R18, R21, R24, R25, R30, R31: 820; 0204/7
R13: 10K; 0204/7
RE1: 820; 0204/7
RFREE1, RFREE2: 820; 0204/7
RO4: 1K; 0204/7
RPFREE1, RPFREE2: 10K; 0204/7
S1, S2: DTS-3
U1: ARDUINO HEADER; DUEMILANOVE_VIAS
VDD: HEADER-1P-32; 1P-60/32MIL
VIN: HEADER-1P-32; 1P-60/32MIL

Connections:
3V3: 3V3.P$1, U1.3.3V, U1.A2
CE0: J13.6, U1.D10 (*D10)
CE1: J13.7, LEDCE1.K (C)
DQ: IC1.2 (DQ), J2.2, OW.1
FREE1: J13.2, LEDFREE1.K (C)
FREE1-PI: JFREE1.P$1, RPFREE1.2, S1.1
FREE2: J13.8, LEDFREE2.K (C)
FREE2-PI: JFREE2.P$1, RPFREE2.1, S2.1
GND: GND.P$1, I2C-OLED.4, IC1.1 (GND), J2.3, LED1.K (C), LED2.K (C), LED3.K (C), LED4.K (C), LED5.K (C), LED6.K (C), LED7.K (C), LED8.K (C), LED9.K (C), R12.1, R14.2, S1.2, S2.2, U1.GND@0 (GND), U1.GND@1 (GND), U1.GND@2 (GND)
IO4: J12.1, LEDO9.K (C)
IO17: J12.2, LED17.K (C)
IO18: J12.3, LED18.K (C)
IO21: J12.4, LED21.K (C)
IO22: J12.5, LED22.K (C)
IO23: J12.6, LED23.K (C)
IO24: J12.7, LED24.K (C)
IO25: J12.8, LED25.K (C)
IO28: J11.1, LED28.K (C)
IO29: J11.2, LED29.K (C)
IO30: J11.3, LED30.K (C)
IO31: J11.4, LED31.K (C)
MISO: J13.4, U1.D12
MOSI: J13.3, U1.D11 (*D11)
unnamed: R11.1, R12.2, U1.A1
unnamed: R10.1, R11.2, U1.A0
unnamed: LED1.A, R1.1
unnamed: R13.2, R14.1, U1.A3
unnamed: LED2.A, R2.1
unnamed: JP-TX.2, JTXD.1
unnamed: LED3.A, R3.1
unnamed: LED4.A, R4.1
unnamed: LED5.A, R5.1
unnamed: JP-RX.2, JRXD.1
unnamed: LED6.A, R6.1
unnamed: LED7.A, R7.1
unnamed: LED8.A, R8.1
unnamed: LED9.A, R9.1
unnamed: LEDO9.A, RO4.1
unnamed: LED17.A, R17.1
unnamed: LED18.A, R18.1
unnamed: LED21.A, R21.1
unnamed: LED22.A, R22.1
unnamed: LED23.A, R23.1
unnamed: LED24.A, R24.1
unnamed: R9.2, U1.D9 (*D9)
unnamed: R8.2, U1.D8
unnamed: R7.2, U1.D7
unnamed: R6.2, U1.D6 (*D6)
unnamed: R5.2, U1.D5 (*D5)
unnamed: R4.2, U1.D4
unnamed: R3.2, U1.D3 (*D3)
unnamed: R2.2, U1.D2
unnamed: LED25.A, R25.1
unnamed: LEDFREE1.A, RFREE1.1
unnamed: LED28.A, R28.1
unnamed: LED29.A, R29.1
unnamed: LED30.A, R30.1
unnamed: LED31.A, R31.1
unnamed: LEDCE1.A, RE1.1
unnamed: LEDFREE2.A, RFREE2.1
RXD-PI: JP-RX.1, JRXD.2, U1.TX
SCL: I2C-OLED.1, POGO.1, U1.A5
SCLK: J13.5, U1.D13
SDA: I2C-OLED.2, POGO.2, U1.A4
TXD-PI: JP-TX.1, JTXD.2, U1.RX
VDD: I2C-OLED.3, IC1.3 (VDD), J2.1, R10.2, R17.2, R18.2, R21.2, R22.2, R23.2, R24.2, R25.2, R28.2, R29.2, R30.2, R31.2, RE1.2, RFREE1.2, RFREE2.2, RO4.2, RPFREE1.1, RPFREE2.2, U1.5V, VDD.P$1
VIN: R1.2, R13.1, U1.VIN, VIN.P$1

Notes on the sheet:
ArduiPi Test Shield
1.3

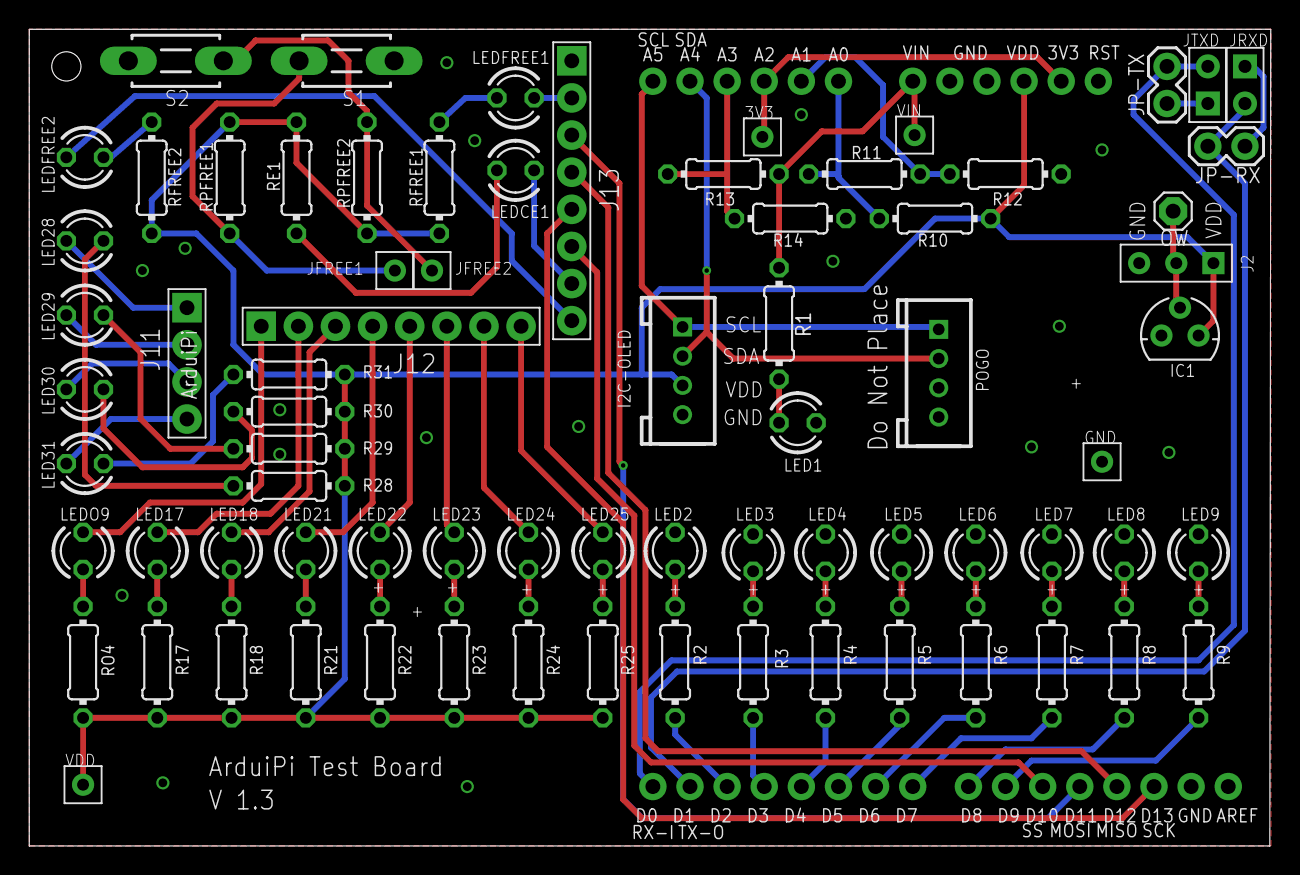
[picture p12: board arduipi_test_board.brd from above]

Board: 2 copper layers, 85.0 x 55.9 mm, 76 parts (0 on the bottom side), 67 nets.

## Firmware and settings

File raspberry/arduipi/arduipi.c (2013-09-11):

/* ======================================================================
Program : arduipi.c
Purpose : arduipi demo program for ArduiPi project
Version : 1.0
Author  : (c) Charles-Henri Hallard
Comments: This program is written for the open source project ArduiPi 
					you can find documentation and all code on my github located at
					https://github.com/hallard/arduipi

					You can use or distribute this code unless you leave this comment
					too see this code correctly indented, please use tab values of 2
 
====================================================================== */
#include <stdio.h>
#include <stdint.h>
#include <sys/stat.h>
#include <unistd.h>
#include <stdio.h>
#include <linux/i2c-dev.h>
#include <fcntl.h>
#include <unistd.h>
#include <stdlib.h>
#include <stdarg.h>
#include <errno.h>
#include <string.h>
#include <signal.h>
#include <syslog.h>
#include <getopt.h>
#include <sys/ioctl.h>
#include <linux/types.h>
#include <linux/spi/spidev.h>
#include <fcntl.h>


// ----------------
// Constants
// ----------------
#define true 1
#define false 0

// Program name and version
#define PRG_NAME    "arduipi"
#define PRG_VERSION	"1.0"

// Define i2c default device & address
#define I2C_DEVICE_0 	"/dev/i2c-0"
#define I2C_DEVICE_1 	"/dev/i2c-1"
#define I2C_ADDRESS	0x2A

// Define spi default device 
#define SPI_DEVICE_1	"/dev/spidev0.1"
#define SPI_DEVICE_0	"/dev/spidev0.0"
#define SPI_MODE			0
#define SPI_BITS_WORD	8	
#define SPI_SPEED			1000000
#define SPI_DELAY			0

// Arduipi defined command
#define ARDUIPI_CMD_PING 0xe0

// receive buffer size
#define BUFFER_SIZE	32

// Program mode function
enum mode_e 	{ MODE_QUICK_ACK, MODE_READ_ACK, MODE_SET, MODE_GET, MODE_GET_WORD };

// Program protocol 
enum proto_e 	{ PROTO_I2C, PROTO_SPI, PROTO_SERIAL };

// Config Option structure parameters
struct 
{
	char port[128];	// device name ex:/dev/i2c-0
	char data[BUFFER_SIZE];	// Data buffer
	int datasize;
	int address;					// i2c slave address
	int mode;							// program mode functionnality
	char *mode_str;				// program mode functionnality human readable
	int proto;						// protocol used
	char *proto_str;			// protocol mode functionnality human readable
	uint8_t spi_mode;
	uint8_t spi_bits;			// spi bits per word
	uint32_t spi_speed ;	// spi frequency max
	uint16_t spi_delay;		// spi delay
	int verbose;					// verbose mode, speak more to user
	int hexout;

} opts = {
	.port = "",
	.data = "",
	.datasize =0,
	.address = I2C_ADDRESS,
	.mode = MODE_QUICK_ACK,
	.mode_str = "ack",
	.proto = PROTO_I2C,
	.proto_str = "i2c",
	.spi_mode = SPI_MODE,
	.spi_bits = SPI_BITS_WORD,
	.spi_speed = SPI_SPEED,
	.spi_delay = SPI_DELAY,
	.verbose = false,
	.hexout = false
};


// ======================================================================
// Global vars 
// ======================================================================
int 	g_fd_device; 	// handle
int		g_exit_pgm;		// indicate end of the program
int		g_pi_rev;			// Rasberry Pi Board Revision

/* ======================================================================
Function: log_syslog
Purpose : write event to syslog
Input 	: stream to write if needed
					string to write in printf format
					printf other arguments
Output	: -
Comments: 
====================================================================== */
void log_syslog( FILE * stream, const char *format, ...)
{
	static char tmpbuff[512]="";
	va_list args;

	// do a style printf style in ou buffer
	va_start (args, format);
	vsnprintf (tmpbuff, sizeof(tmpbuff), format, args);
	tmpbuff[sizeof(tmpbuff) - 1] = '\0';
	va_end (args);

	// Write to logfile
	openlog( PRG_NAME, LOG_PID|LOG_CONS, LOG_USER);
 	syslog(LOG_INFO, tmpbuff);
 	closelog();
 	
 	// stream passed ? write also to it
 	if ((stream && opts.verbose) || stream == stdout ) 
 	{
 		fprintf(stream, tmpbuff);
 		fflush(stream);
 	}
}


/* ======================================================================
Function: clean_exit
Purpose : exit program 
Input 	: exit code
Output	: -
Comments: 
====================================================================== */
void clean_exit (int exit_code)
{
	// close i2c if opened 
  if (g_fd_device)
  {
		// then close
  	close(g_fd_device);
  }

	if ( exit_code != EXIT_SUCCESS)
		log_syslog(stdout, "Closing %s due to error\n", PRG_NAME);
	
	exit(exit_code);
}

/* ======================================================================
Function: fatal
Purpose : exit program due to a fatal error
Input 	: string to write in printf format
					printf other arguments
Output	: -
Comments: 
====================================================================== */
void fatal (const char *format, ...)
{
	char tmpbuff[512] = "";
	va_list args;

	va_start(args, format);
	vsnprintf(tmpbuff, sizeof(tmpbuff), format, args);
	tmpbuff[sizeof(tmpbuff) - 1] = '\0';
	va_end(args);

	// Write to logfile
	openlog( PRG_NAME, LOG_PID | LOG_CONS, LOG_USER);
 	syslog(LOG_INFO, tmpbuff);
 	closelog();

	fprintf(stderr,"\r\nFATAL: %s \r\n", tmpbuff );
	fflush(stderr);

	clean_exit(EXIT_FAILURE);
}


/* ======================================================================
Function: isr_handler
Purpose : Interrupt routine Code for signal
Input 	: -
Output	: -
Comments: 
====================================================================== */
void isr_handler (int signum)
{
	// Does we received CTRL-C ?
	if ( signum==SIGINT || signum==SIGTERM)
	{
		// Indicate we want to quit
		g_exit_pgm = true;
		
		log_syslog(NULL, "Received SIGINT/SIGTERM");
	}
	// Our receive buffer is full
	else if (signum == SIGIO)
	{
		log_syslog(NULL, "Received SIGIO");
	
	}
	
}

/* ======================================================================
Function: i2c_init
Purpose : initialize i2c port for communication
Input 	: -
Output	: i2c Port Handle
Comments: -
====================================================================== */
int i2c_init(void)
{
	int fd ;

  // Open i2c bus
  if ( (fd = open(opts.port, O_RDWR)) < 0 ) 
  	fatal( "i2c_init device %s: %s", opts.port, strerror(errno));

	// set slave address
	if ( ioctl(fd, I2C_SLAVE, opts.address) < 0)
		fatal( "i2c_init error setting slave address 0x%02X : %s", opts.address, strerror(errno));

 	return fd ;
}

/* ======================================================================
Function: spi_init
Purpose : initialize spi port for communication
Input 	: -
Output	: spi Port Handle
Comments: -
====================================================================== */
int spi_init(void)
{
	int fd ; 
	int ret;
	uint8_t mode;			// spi mode
	uint8_t bits;			// spi bits per word

  // Open spi bus
  if ( (fd = open(opts.port, O_RDWR)) < 0 ) 
  	fatal( "spi_init %s: %s", opts.port, strerror(errno));

	// set spi mode
	ret = ioctl(fd, SPI_IOC_WR_MODE, &opts.spi_mode);
	if (ret == -1)
		fatal( "spi_init %s : error writing mode %02X : %s",  opts.port, opts.spi_mode, strerror(errno));

	// read the value we set and check it is the same
	ret = ioctl(fd, SPI_IOC_RD_MODE, &mode);
	if (ret == -1 || mode !=opts.spi_mode )
		fatal( "spi_init %s : error checking mode %02X, found %02X : %s",  opts.port, opts.spi_mode, mode, strerror(errno));

	// set spi bits per word
	ret = ioctl(fd, SPI_IOC_WR_BITS_PER_WORD, &opts.spi_bits);
	if (ret == -1)
		fatal( "spi_init %s : error setting write bits per word %d : %s",  opts.port, opts.spi_bits, strerror(errno));

	// read the value we set and check it is the same
	ret = ioctl(fd, SPI_IOC_RD_BITS_PER_WORD, &bits);
	if (ret == -1 || bits != opts.spi_bits )
		fatal( "spi_init %s : error checking bits per word %d, found %d : %s",  opts.port, opts.spi_bits, bits, strerror(errno));

	// set spi max speed hz
	ret = ioctl(fd, SPI_IOC_WR_MAX_SPEED_HZ, &opts.spi_speed);
	if (ret == -1)
		fatal( "spi_init %s : error setting write max speed %d Hz: %s",  opts.port, opts.spi_speed, strerror(errno));

	// read the value we set and check it is the same
	ret = ioctl(fd, SPI_IOC_RD_MAX_SPEED_HZ, &opts.spi_speed);
	if (ret == -1 )
		fatal( "spi_init %s : error setting read max speed %d KHz, %s",  opts.port, opts.spi_speed, strerror(errno));

 	return fd ;
}

/* ======================================================================
Function: charToHexDigit
Purpose : convert char to hex value
Input 	: char
Output	: byte value
Comments: 
====================================================================== */
unsigned char charToHexDigit(char c) 
{
	unsigned char ret ;
	
	// parse to lower case
	if (c >= 'A' && c <= 'F')
		c= c - 'A' + 'a';
 
  if (c >= 'a') 
    ret = c - 'a' + 10; 
  else 
    ret = c - '0'; 

	return (ret);
} 

/* ======================================================================
Function: get_pi_version
Purpose : Get Raspberry Pi Revision Board Version
Input 	: -
Output	: Raspberry Pi revision (1 or 2)
Comments: 
====================================================================== */
// Get raspberry PI model version
int get_pi_version( void ) 
{ 
	int rev = 0;
	char buff[512];
	char * p;
	char * pend;
	
	FILE * fd ;

	// do some clean up
	memset(buff,0,sizeof(buff));

	fd = fopen("/proc/cpuinfo","r");

	// Opened successfully
	if( fd )
	{
		//printf("File opened successfully through fopen()\n");
		
		// parse each line until we the end or we find the good one
		while( fgets(buff, sizeof(buff), fd) != NULL && rev ==0 ) 
		{
			// search 
			if( (strstr(buff, "Revision" )) != NULL )  
			{
				// point to the separator ":" format is has follow
				// Revision        : 000f
				if ( (p = strtok( buff, ":")) != NULL )
				{
					// Ok get value
					if ( (p = strtok( NULL, ":")) != NULL )
					{
						// Revision Version is in hex format so put 0x before the number
						*p   = 'x';
						*--p = '0';
						
						// convert to number
						rev = strtol(p, &pend, 16);
						
						//printf("rev=%d 0x%04x\n", rev, rev);
						
						// not Okay ?
						if ( !*pend )
						{
							rev= 0;
						}
						else
						{
							// Revision 1 or 2 ?
							rev = (rev < 4 ) ? 1 : 2 ;
						}
					}
				}
			}
		}

		// Close the file.
		if(fd) 
		{
			fclose(fd);
		}
	}

	return rev;
} 



/* ======================================================================
Function: usage
Purpose : display usage
Input 	: program name
Output	: -
Comments: 
====================================================================== */
void usage( char * name)
{

	printf("%s\n", PRG_NAME );
	printf("Usage is: %s [options] [protocol] [mode] [-d device] [-a address] [-t data]\n", PRG_NAME);
	printf("  --<D>evice   : device name, i2c or spi\n");
	printf("  --<a>ddress  : i2c device address (default 0x2A)\n");
	printf("  --<d>data    : data to send\n");
	printf("protocol is:\n");
	printf("  --<I>2c      : set protocol to i2c (default)\n");
	printf("  --<S>pi      : set protocol to spi\n");
	printf("mode is:\n");
	printf("  --<s>et value: set value (byte or word type determined by data size)\n");
	printf("  --<g>etbyte  : get byte value\n");
	printf("  --<G>getword : get word value\n");
	printf("  --<q>uick    : i2c quick check device\n");
	printf("  --ac<k>      : i2c check if device sent ack\n");
	printf("Options are:\n");
	printf("  --ma<x>speed : max spi speed (in KHz)\n");
	printf("  --dela<y>    : spi delay (usec)\n");
	printf("  --<b>its     : spi bits per word\n");
	printf("  --<l>oop     : spi loopback\n");
	printf("  --cp<H>a     : spi clock phase\n");
	printf("  --cp<O>l     : spi clock polarity\n");
	printf("  --<L>sb      : spi least significant bit first\n");
	printf("  --<C>s-high  : spi chip select active high\n");
	printf("  --<3>wire    : spi SI/SO signals shared\n");
	printf("  --<N>o-cs    : spi no chip select\n");
	printf("  --<R>eady    : spi Ready\n");
	printf("  --<v>erbose  : speak more to user\n");
	printf("  --he<X>      : show return values in hexadecimal format\n");
	printf("  --<V>ersion  : show program version and Raspberry Pi revision\n");
	printf("  --<h>elp\n");
	printf("<?> indicates the equivalent short option.\n");
	printf("    long options always in lowercase\n");
	printf("Short options are prefixed by \"-\" instead of by \"--\".\n");
	printf("Example :\n");
	printf( "%s --i2c --getbyte --hex --data 0xe0\nSend a ping command and return ping value in hex format\n", PRG_NAME);
//	printf( "%s -m r -v\nstart %s to wait for a value, then display it and exit\n", PRG_NAME, PRG_NAME);
}


/* ======================================================================
Function: parse_args
Purpose : parse argument passed to the program
Input 	: -
Output	: -
Comments: 
====================================================================== */
void parse_args(int argc, char *argv[])
{

	static struct option longOptions[] =
	{
		{"device" 	,required_argument, 0, 'D' },
		{"data"   	,required_argument, 0, 'd' },
		{"verbose"	,no_argument			,	0, 'v' },
		{"version"	,no_argument			,	0, 'V' },
		{"address"	,required_argument, 0, 'a' },
		{"i2c"    	,no_argument			,	0, 'I' },
		{"spi"    	,no_argument			,	0, 'S' },
		{"set"    	,no_argument			,	0, 's' },
		{"getbyte"	,no_argument			,	0, 'g' },
		{"getword"	,no_argument			, 0, 'G' },
		{"quick"  	,no_argument			,	0, 'q' },
		{"ack"    	,no_argument			, 0, 'k' },
		{"help"			,no_argument			,	0, 'h' },
		{"maxspeed"	,required_argument, 0, 'x' },
		{"delay"  	,required_argument, 0, 'y' },
		{"bits"   	,required_argument, 0, 'b' },
		{"loop"		  ,no_argument			, 0, 'l' },
		{"cpha"		  ,no_argument			, 0, 'H' },
		{"cpol"		  ,no_argument			, 0, 'O' },
		{"lsb"			,no_argument			, 0, 'L' },
		{"cs-high"	,no_argument			, 0, 'C' },
		{"3wire"		,no_argument			, 0, '3' },
		{"no-cs"		,no_argument			, 0, 'N' },
		{"ready"		,no_argument			, 0, 'R' },
		{"hex"			,no_argument			, 0, 'X' },
		
		{0, 0, 0, 0}
	};

	int optionIndex = 0;
	int c;
	char * pEnd;
	
	// By default set the correct I2C device function of Pi version

	while (1) 
	{
		/* no default error messages printed. */
		opterr = 0;

		c = getopt_long(argc, argv, "D:d:vVa:x:y:b:ISsgGqkhlHOLC3NRX", longOptions, &optionIndex);

		if (c < 0)
			break;

		switch (c) 
		{
			case 'v':	opts.verbose = true;	break;

			
			case 's': opts.mode = MODE_SET				; 	opts.mode_str = "set"				; break;
			case 'k': opts.mode = MODE_READ_ACK	; 	opts.mode_str = "read ack"	; break;
			case 'q': opts.mode = MODE_QUICK_ACK	; 	opts.mode_str = "quick ack"	; break;
			case 'g': opts.mode = MODE_GET				; 	opts.mode_str = "get byte"	; break;
			case 'G': opts.mode = MODE_GET_WORD	; 	opts.mode_str = "get word"	; break;
			case 'I': opts.proto= PROTO_I2C    	; 	opts.proto_str= "i2c"     	; break;
			case 'l': opts.spi_mode |= SPI_LOOP			; break;
			case 'H': opts.spi_mode |= SPI_CPHA			; break;
			case 'O': opts.spi_mode |= SPI_CPOL			; break;
			case 'L': opts.spi_mode |= SPI_LSB_FIRST	;	break;
			case 'C': opts.spi_mode |= SPI_CS_HIGH		;	break;
			case '3': opts.spi_mode |= SPI_3WIRE			;	break;
			case 'N': opts.spi_mode |= SPI_NO_CS			;	break;
			case 'R': opts.spi_mode |= SPI_READY			;	break;
			case 'X': opts.hexout = true		;	break;
			
			
			// SPI init default bus
			case 'S': 
				opts.proto= PROTO_SPI ; 
				opts.proto_str= "spi";  

				// if bus still i2c, default to spi0
				// /dev/i2c-x -> i is th 5th char
				if ( opts.port[5] == 'i' )
					strcpy(opts.port, SPI_DEVICE_0);
					
			break;

			
			// i2c slave address
			case 'a':
				opts.address = strtol(optarg,&pEnd,0);
				
				if ( !pEnd || opts.address < 1 || opts.address > 0x7F )
				{
						fprintf(stderr, "--address %d (0x%02x) ignored.\n", opts.address, opts.address);
						fprintf(stderr, "--address must be between 1 and 255 or 0x01 and 0xff\n");
						opts.address = I2C_SLAVE;
						fprintf(stderr, "--setting slave to default 0x%02x\n", opts.address);
				}
			break;

			// spi max speed
			case 'x':
				opts.spi_speed = strtol(optarg,&pEnd,0) ;
				
				if ( !pEnd || opts.spi_speed < 1 || opts.spi_speed > 10000 )
				{
						fprintf(stderr, "--maxspeed %d Khz ignored.\n", opts.spi_speed);
						fprintf(stderr, "--maxspeed must be between 1 and 10000 (KHz)\n");
						opts.spi_speed = SPI_SPEED;
						fprintf(stderr, "--setting max speed to default %d Khz\n", opts.spi_speed/1000);
				}
				else
				{
					opts.spi_speed *= 1000;
				}
			break;

			// spi delay 
			case 'y':
				opts.spi_delay = strtol(optarg,&pEnd,0) ;
				
				if ( !pEnd || opts.spi_delay < 0 )
				{
						fprintf(stderr, "--delay %dus ignored.\n", opts.spi_delay);
						opts.spi_delay = SPI_DELAY;
						fprintf(stderr, "--setting delay to default %d us\n", opts.spi_delay);
				}
			break;

			// spi bits per word 
			case 'b':
				opts.spi_bits = strtol(optarg,&pEnd,0) ;
				
				if ( !pEnd || opts.spi_bits < 0 || opts.spi_bits > 64 )
				{
						fprintf(stderr, "--bits %d ignored.\n", opts.spi_bits);
						opts.spi_delay = SPI_BITS_WORD;
						fprintf(stderr, "--setting bits per word to default %d us\n", opts.spi_bits);
				}
			break;

			// Device name
			case 'D':
				strncpy(opts.port, optarg, sizeof(opts.port) - 1);
				opts.port[sizeof(opts.port) - 1] = '\0';
			break;

			// Data
			case 'd':
			{
				int ishex = false;
				char * p = opts.data;

			
				// Check correct size
				if ( strlen (optarg) >= 2)
				{
					// is it a hex string 
					if (optarg[0] == '0' && optarg[1] == 'x' )
						ishex = true;
				}
				
				if (ishex)
				{
					// put hex value into buffer data
					for (c = 2 ; optarg[c] != '\0' ; c += 2, p++)    
					{
						// even number of hex char
						if ( !optarg[c+1] )
						{
							*p = charToHexDigit(optarg[c]) ; 
							c+=2;
							break;
						}
						else
						{
							*p = charToHexDigit(optarg[c]) * 16 + charToHexDigit(optarg[c+1]); 
						}
					}
					
					opts.datasize = (c/2)- 1;
				}
				else
				{
					// copy the string
					opts.datasize = strlen(optarg);
					strncpy (opts.data, optarg, opts.datasize+1);
					strncat (opts.data, "\n", 1);
					opts.datasize++;
				}
			}
			break;

			// version
			case 'V':
			{
				printf("%s v%s\n", PRG_NAME, PRG_VERSION);
				printf("Raspberry Board Revision : %04x\n", g_pi_rev );
				exit(EXIT_SUCCESS);
			}
			break;

			// help
			case 'h':
				usage(argv[0]);
				exit(EXIT_SUCCESS);
			break;
			
			case '?':
			default:
				fprintf(stderr, "Unrecognized option.\n");
				fprintf(stderr, "Run with '--help'.\n");
				exit(EXIT_FAILURE);
			break;
		}
	} /* while */

	
	if (opts.verbose)
	{
		
		if ( opts.proto == PROTO_I2C )
		{
			printf("-- i2c Stuff -- \n");
			printf("i2c bus       : %s\n", opts.port);
			printf("slave address : 0x%02X\n", opts.address);
		}
		if ( opts.proto == PROTO_SPI )
		{
			printf("-- spi Stuff -- \n");
			printf("spi bus       : %s\n", opts.port);
			printf("spi mode      : %d\n", opts.spi_mode);
			printf("bits per word : %d\n", opts.spi_bits);
			printf("max speed     : %d Hz (%d KHz)\n", opts.spi_speed, opts.spi_speed/1000);
		}
				
		printf("mode          : %s\n", opts.mode_str);
		printf("protocol      : %s\n", opts.proto_str);
		printf("verbose       : %s\n", opts.verbose? "yes" : "no");
		printf("data (%02i)     : ", opts.datasize);
		
		if (opts.datasize >0 )
		{
			for (c = 0; c <opts.datasize ; c++)    
				printf("0x%02X ", opts.data[c]);
							
			printf("\n");
		}
		else
		{
			printf("NULL\n");
		}

	}	
}
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
int main(int argc, char **argv)
{
	struct sigaction exit_action;
  int n;
	char	buff[BUFFER_SIZE];

	g_fd_device = 0;
	g_exit_pgm = false;

	// clean up our buffer size
	bzero(buff, BUFFER_SIZE);

	// Get Raspberry Board Revision
	g_pi_rev = get_pi_version() ;
		
	// No Raspberry Board ?
	if ( g_pi_rev == 0 ) 
	{
		printf("Error Unable to find Raspberry Board Revision\n");
		clean_exit(EXIT_FAILURE);
	}
	
	// Set i2c device default bus depending on PI version
	strcpy(opts.port, g_pi_rev >= 2 ? I2C_DEVICE_1 : I2C_DEVICE_0 );
	
	// get command line args
	parse_args(argc, argv);

	// Set up the structure to specify the exit action.
	exit_action.sa_handler = isr_handler;
	sigemptyset (&exit_action.sa_mask);
	exit_action.sa_flags = 0;
	sigaction (SIGTERM, &exit_action, NULL);
	sigaction (SIGINT,  &exit_action, NULL); 

	// do i2c job
	if ( opts.proto == PROTO_I2C )
		do_i2c();

	// do spi job
	if ( opts.proto == PROTO_SPI )
		do_spi();
		
	// Do while not end 
	// this is for demo purpose, you can do whatever you like in this loop
	while ( ! g_exit_pgm ) 
	{
		// example Read adc value from arduino
		n = i2c_smbus_read_byte_data(g_fd_device, 0x01);

		// We want to display results on stdout even if we are deamon ?
		if (opts.verbose)
		{
			log_syslog(stdout, "Received 0x%02x from slave\n", n);
		}

		// Do it again in 5 seconds
		sleep(5);

	}

  log_syslog(stderr, "Program terminated\n");

  clean_exit(EXIT_SUCCESS);

  // avoid compiler warning
  return (0);
}

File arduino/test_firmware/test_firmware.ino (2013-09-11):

/* ========================================================================
Program : i2c_demo.ino
Purpose : wait for i2c command, parse command and do action 
Version : 1.0
Author  : (c) Charles-Henri Hallard (http://hallard.me)
Comments: this file belong to the ArduiPi project
		you will find more information on this project on my blog and github
		http://hallard.me/arduipi
		https://github.com/hallard/arduipi
	  You can use or distribute this code unless you leave this comment
	  too see this code correctly indented, please use Tab values of 2
=========================================================================== */

#include <arduino.h>
#include <Wire.h>
#include <SPI.h>
#include <DS2482.h>
#include <SeeedGrayOLED.h>

// ======================================================================
// Constants definition
// ======================================================================
#define  SLAVE_ADDRESS	0x2a  /* slave address,any number from 0x01 to 0x7F */
#define  CMD_MAX_SIZE   16  	/* max command size */
#define  MAX_SENT_BYTES 3
#define  IDENTIFICATION 0x0D
#define  LOOP_DELAY 	2000 		/* by default blink led every 2 seconds */
#define  BLINK_VALUE	LOOP_DELAY / 2 

//#define	 DEBUG_SERIAL

#define	 CMD_ARDUINO_PIN0		0x00
#define	 CMD_ARDUINO_PIN18	0x12
#define	 CMD_PORT_PIN0			0x00
#define	 CMD_PORT_PIN7			0x07
#define	 CMD_A0_ARDUINO			0xA0
#define	 CMD_A6_ARDUINO			0xA6
#define	 CMD_AVR_CMD_PORTB	0x1B
#define	 CMD_AVR_CMD_PORTC	0x1C
#define	 CMD_AVR_CMD_PORTD	0x1D
#define	 CMD_AVR_CMD_DDRB		0x2B
#define	 CMD_AVR_CMD_DDRC		0x2C
#define	 CMD_AVR_CMD_DDRD		0x2D
#define	 CMD_A0_AVR					0xC0
#define	 CMD_A6_AVR					0xC6
#define	 CMD_DDR0_PIN				0xD0
#define	 CMD_DDR7_PIN				0xD7
#define	 CMD_DDR_ARDUINO		0xDD
#define	 CMD_PING						0xE0
#define	 CMD_PORT_VALUE			0xF0
#define	 CMD_DDR_VALUE			0xFD
#define	 CMD_SEPARATOR			0xFF


// Define various ADC prescaler
#define PS_16  ((1 << ADPS2))
#define PS_32  ((1 << ADPS2) | (1 << ADPS0))
#define PS_64  ((1 << ADPS2) | (1 << ADPS1))
#define PS_128 ((1 << ADPS2) | (1 << ADPS1) | (1 << ADPS0))

#define pinLed 2

// State machine for parsing received command
enum parse_cmd	{ PARSE_CMD, PARSE_DATA, PARSE_NEXT, PARSE_ALL, PARSE_ERR, PARSE_OK };

// ======================================================================
// Volatile Global vars, may be used in interrupts
// standard Global vars 
// ======================================================================
volatile byte g_i2c_rx_buf[CMD_MAX_SIZE];	// i2c command sent by the master
volatile byte g_i2c_rx_len=0;							// i2c command len sent by the master
volatile byte g_spi_rx_buf[CMD_MAX_SIZE];	// spi command sent by the master
volatile byte g_spi_rx_len=0;							// spi command len sent by the master
volatile byte g_ser_rx_buf[CMD_MAX_SIZE];	// serial command sent by the master
volatile byte g_ser_rx_len=0;							// serial command len sent by the master
volatile boolean g_i2c_new = false;			// new i2c command received to treat
volatile boolean g_spi_new = false;			// new spi command received to treat
volatile boolean g_ser_new = false;			// new serial command received to treat
volatile byte g_i2c_tx_len = 0;						// lenght of i2c data to return to master
volatile byte g_spi_tx_len = 0;						// lenght of spi data to return to master
volatile byte g_ser_tx_len = 0;						// lenght of serial data to return to master
//volatile byte g_spi_pos = 0;						// SPI pointer on receive buffer
volatile byte g_cmd_err = 0;							// global command error

volatile long g_vcc = 0;									// vcc value (read from ADC)

byte g_i2c_tx_buf[CMD_MAX_SIZE]; 					// i2c buffer of returned data to master
byte g_spi_tx_buf[CMD_MAX_SIZE]; 					// spi buffer of returned data to master
byte g_ser_tx_buf[CMD_MAX_SIZE]; 					// serial buffer of returned data to master
byte g_cmd_size;													// new command size (can identify quickly simple command)
byte g_cmd_send= false;									// new data to send to master
byte g_ping = 0x2a;												// default ping value data to respond
byte g_ds18b20[8] ;
char buff[17];


DS2482 ds(0);

// Test passed variable flags
volatile boolean g_i2c_tested = false;			// indicate that I2C test passed
volatile boolean g_spi_tested = false;			// indicate that SPI test passed
volatile boolean g_ser_tested = false;			// indicate that serial test passed
volatile boolean g_1w_tested  = false;			// indicate that 1-Wire test passed
volatile boolean g_analog_tested  = false;	// indicate that analog input test passed



/* ======================================================================
Function: readADC
Purpose : Read Analog Avlue
Input 	: -
Output	: value readed
Comments: Channel needed to read has been selected before
====================================================================== */
uint16_t readADC()
{
	uint8_t low, high;

	// Start Convertion
	ADCSRA |= _BV(ADSC); 
	
	// wait end
	while (bit_is_set(ADCSRA,ADSC));
	
	// read low first
	low  = ADCL;
	high = ADCH;

	return ((high << 8) | low);
}
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

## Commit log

2012-10-04 Preliminary Schematic
    [ArduiPi.brd, ArduiPi.sch]
2012-11-06 Reordered Componnents on PCB for bettre view
    [ArduiPi.brd]
2012-11-06 Final Design
    Final Design
    [ArduiPi.brd, ArduiPi.sch]
2012-11-07 Added Pads
    Added pads for One Wire and Prototyping area
    [ArduiPi.brd, ArduiPi.sch]
2013-02-28 Prototype Board
    ArduiPi First Prototype Board
    [ArduiPi.brd, ArduiPi.sch]
2013-03-05 2nd Prototype Board
    2nd Version of the prototype board, near final version.
    Changes :
    - Removed R3 pullup from the output of the SFH6206
    - Changed Level Shifting of RX line, now goes through 2 new FET
    transistors Q7 and Q6 (BSS138 like I2C) and removed the connection of RX
    from the TXB0108 (U5)
    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
    [ArduiPi.brd, ArduiPi.sch]
2013-06-29 ArduiPi Production Version V0.9d
    ArduiPi Production Version V0.9d
    [ArduiPi.brd, ArduiPi.sch]
2013-06-29 ArduiPi Test Board Shield
    ArduiPi Test Board Shield for testing ArduiPi board after production
    [arduipi_test_board.brd, arduipi_test_board.sch]
2013-07-30 Modification for SPI return test
2013-07-30 Bug Fixes
    Compilation problem
    put the serial to 9600 for test board
    [test_firmware.ino]
2013-08-08 Bug Fixe
    Set port D2..D9 to output in setup
    Removed I2C speed of 400KHz
    [test_firmware.ino]
2013-09-11 Set SPI speed to 1MHZ and limit I2C display
    Set SPI speed to 1MHZ
    Refresh I2C display only after received I2C test command to avoid I2C
    collision
    [test_firmware.ino]
2013-09-11 Set SPI Speed to 1MHZ, Avoid i2C collisions with OLED
    Set SPI Speed to 1MHZ
    Display enabled only when received 1st I2C command to avoid I2C
    collisions
    [test_firmware.ino]
2013-09-11 Updated to avoid I2C collision with OLED i2c
    change into IRQ, if we detect I2C detect issued from Pi we validate I2C
    test and start refresh OLED
    [test_firmware.ino]
2013-09-11 Set SPI speed to 1MHZ / removed i2C Ping
    removed i2c ping test
    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
2013-09-11 bug fix on SPI set bus speed
    launching tool trying to set spi speed with --maxspeed 1000 was not
    working du to a bug on parsing option
    [arduipi.c]
2014-03-03 Creation
    Auto Reset file to enable firmware upload to Arduino from Arduino IDE
    using Raspberry PI Serial UART
2014-03-03 Creation
    Script to Reset Arduino without programming it
2014-03-03 Creation
    ArduiPi V1.0 Schematics
2014-03-22 Revision 1.1 of the board
    [ArduiPi V1.1.brd, ArduiPi V1.1.sch]
2014-03-22 ArduiPi Arduino Bootloader
    ArduiPi bootloader
    Modified to have 2 flash led on D13 and blinking on uploading
2014-03-22 Revision 1.1 of the board BOM file
    [Arduipi-V1.1-BOM.xlsx]
2014-03-22 Updated for V1.1 board

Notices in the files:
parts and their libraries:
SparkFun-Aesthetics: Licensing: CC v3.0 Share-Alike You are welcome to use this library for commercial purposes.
